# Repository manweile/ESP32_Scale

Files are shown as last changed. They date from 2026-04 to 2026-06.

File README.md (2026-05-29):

# ESP32 Propane Scale

Compact ESP32-based propane tank scale that measures tank weight, subtracts the tank tare, and reports the propane weight and fill percentage.

This version is serial monitor based, and serves as starting point for wifi and web ble versions.

## Versions

1. Serial monitor
2. Web BLE
3. Wifi

## Quick highlights

- Weighs tanks using four load cells + HX711 amplifier
- Supports automatic and manual calibration workflows
- Saves calibration/tare values to EEPROM
- Built with `arduino-cli` and VS Code tasks for rapid iteration

## Quick Start

1. Install Arduino CLI
2. Install Espressif toolchain
3. Install ESP32 board support and the HX711 library
4. Open this workspace in VS Code. Use the provided tasks to build/flash (see 'Tasks' section)
5. Edit `PropaneScale/config.h` to set the pins and default calibration/tare values before flashing
6. Connect to a serial console at `115200` to interact with the command interface

## Building and Uploading

Building & Uploading can be done with VS Code compound task calls:

- `ESP32 Thing Quick Compile & Quick Flash`
- `ESP32 Thing Clean Rebuild & Quick Flash`
- Refer to building and upload section for details

### Building

Building is being done via arduino-cli.

- Using arduino-cli for convenience
- Have experience with it
- Already installed and configured
- Precludes having to re-learn CMake & Ninja
- Use the included VS Code tasks: `ESP32 Thing Quick Compile`, `ESP32 Thing Clean Rebuild`
- The FQBN (full qualified board name) is hard coded because the project is esp32 specific
- Example arduino-cli build command (used by the tasks):

  ```bash
  arduino-cli compile -v --fqbn esp32:esp32:esp32thing PropaneScale
  ```

### Upload

Uploading is done via esptool.exe

- Planning on eventually using esp tools entirely for build and upload
- Since esp32 is only chip used, it is hard coded, as is the upload speed, write flash location, and binary file
- the *.ino.merged.bin file must be used for an esp32
- Use the include VS Code tasks:
  - `ESP32 Thing Quick Flash`
    - This task uses `esp32-thing-quick-flash.ps1` powershell script, which in turn calls `list_ports.py`
    - These scripts return the com port the esp32 thing is attached to
    - Example cli:

    ```bash
    esptool.exe --chip esp32 --port COM3 --baud 921600 write-flash -z 0x0 D:/MyArduino/Projects/ESP32_Scale/PropaneScale/build/esp32.esp32.esp32thing/PropaneScale.ino.merged.bin
    ```

  - `ESPTool ESP32 COMPort Merged Bin Upload`
    - This task needs com port import
    - The com port input uses `list_ports.py` directly
    - Example cli:

    ```bash
    esptool.exe --chip esp32 --port COM4 --baud 921600 write-flash -z 0x0 D:/MyArduino/Projects/ESP32_Scale/PropaneScale/build/esp32.esp32.esp32thing/PropaneScale.ino.merged.bin
    ```

## Configuration

- Edit `PropaneScale/config.h` to change:
  - `CLK_PIN`, `DOUT_PIN` (HX711 pins)
    - While these can be almost any of the available pins, using 16 & 17 so the JTAG pins (12, 13, 14, 15) remain open
  - `BAUD` (serial baud rate)
    - Needs to be 115200, as that is the hard coded default boot speed of the ESP32 Thing
    - using any other speed results in ascii garbage hen the REST button is hit
  - `DEF_CALIBRATION_FACTOR`
    - Computed by running SparkFun_HX711_Calibration.ino in examples directory and noting the value
  - `DEF_KNOWN_WEIGHT`
    - The sample weight used to compute the default calibration factor
  - `DEF_TANK_TARE`
    - midpoint of average 20 lb tank tares
  - `DEF_MAX_PROPANE`
    - the legal maximum of propane for 20 lb tank: 80% x 20 = 16

## Hardware Summary

- Microcontroller: SparkFun ESP32 Thing (DEV-13907)
- Amplifier: SparkFun HX711 (BOB-13879)
- Load cells: SparkFun 50 kg (SEN-10245) — 4x in a full-bridge arrangement

### HX711 pins (default)

| HX711 | ESP32 |
| --- | --- |
| CLK | GPIO 17 |
| DOUT | GPIO 16 |

## Serial Command Interface

- Commands:
  - `a` — Automatic calibration
  - `c` — Print current runtime values
  - `d` — Reset EEPROM value to default configuration
  - `e` — Print EEPROM values
  - `h` — Print menu
  - `m` — Manual calibration (use `+` / `-`, save with `s`)
  - `k` - Set known weight for calibrations (enter value, `s` to save)
  - `l` — Single reading of propane weight and level
  - `p` — Set tank tare (enter value, `s` to save)
  - `q` — Cancellation for all input workflows
  - `r` — Re-zero scale, `q` to force-confirm
  - `t` - Set tank tare (enter value, `s` to save)

## Output example

```text
Scale load: 39.5 lbs, Calculated propane: 15.7 lbs, Level: 65.4%
```

## Project Layout

- [PropaneScale](PropaneScale): main sketch
- `config.h` (pin and calibration constants)
- Documentation under the `Documentation/` folder
- Examples under the `Examples/` folder

## Development Notes

- This workspace includes tasks for build/flash and a Doxygen setup in `Documentation/Doxygen/`.
- See `Documentation/Copilot/` for notes and design plans.

Contributing

- Fixes, improvements, and pull requests welcome. Please open issues describing bugs or requested features.

License

- This repository does not include a license file. Add one if you intend to publish the code.

---
Updated README: streamlined quick-start, build tasks, and configuration notes.

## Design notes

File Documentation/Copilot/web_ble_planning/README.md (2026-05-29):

# Web BLE Planning (directory)

This directory is the canonical location for all Web Bluetooth planning artifacts for the PropaneScale project.

Place all new or updated web-ble planning files here, including:
- `web-bluetooth-plan.md` (high-level proposal and milestones)
- `asus-tab-a-test-checklist.md` (device-specific test checklists)
- `ble_test_vectors.md` (test payloads and vectors)
- `examples/` (client prototypes, sample pages)

Policy: until further notice, put web BLE documents and examples into this folder so they are easy to find and review.

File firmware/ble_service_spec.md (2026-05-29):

# BLE Service Specification — PropaneScale (Firmware)

This document defines exact UUIDs, characteristic properties, and payload formats for the BLE GATT service the `PropaneScale` ESP32 firmware will expose. This is a protocol specification only — no implementation is included.

Service
- Name: PropaneScale Service (custom)
- UUID (128-bit): 0000FEED-0000-1000-8000-00805F9B34FB

Characteristic summary (all UUIDs are 128-bit within same vendor base):
- Weight (Notify, Read) — UUID: 0000BE01-0000-1000-8000-00805F9B34FB
- Tare Command (Write Without Response) — UUID: 0000BE02-0000-1000-8000-00805F9B34FB
- Calibrate Command (Write) — UUID: 0000BE03-0000-1000-8000-00805F9B34FB
- Raw ADC (Notify, Read) — UUID: 0000BE04-0000-1000-8000-00805F9B34FB
- Sampling Rate (Read/Write) — UUID: 0000BE05-0000-1000-8000-00805F9B34FB
- Battery (Read, Notify) — UUID: 0000BE06-0000-1000-8000-00805F9B34FB
- Device Info / Version (Read) — UUID: 0000BE07-0000-1000-8000-00805F9B34FB

General encoding rules
- Endianness: Little-endian for multi-byte numeric fields.
- Numeric types: use standard sizes (uint8, int16, int32, uint16, uint32, float32 as IEEE-754 where indicated).
- Versioning: each notification payload starts with `uint8 version` (currently `1`).
- Sequence counter: optional `uint16 seq` included in streaming payloads to detect loss.
- All characteristic lengths are fixed where practical to simplify parsing.

Characteristic details

1) Weight — `0000BE01-...`
- Properties: Notify, Read
- Purpose: current processed weight in pounds (float32) with sign support.
- Payload (9 bytes):
  - byte 0: `uint8 version` (1)
  - byte 1-4: `float32 weight_lbs` — weight in pounds (IEEE‑754 float32, little-endian)
  - byte 5-6: `uint16 seq` — packet sequence number (wraps)
  - byte 7-8: `int16 reserved` — reserved (set 0)
- Example: weight = 12.345 lbs → payload fields:
  - `[version=0x01][float32 little-endian of 12.345][seq=0x0001][reserved=0x0000]`
  (Replace the float32 bytes with the IEEE‑754 little-endian representation for the value.)

2) Tare Command — `0000BE02-...`
- Properties: Write Without Response (fast), firmware acts immediately.
- Purpose: request firmware to perform tare (zero) operation.
- Payload (1 byte):
  - byte 0: `uint8 cmd` where 0x01 = TARE_NOW
- Example: to tare, client writes `[0x01]`.
- Security: firmware must validate source and rate-limit successive TARE requests (e.g., minimum 1s between tarries).

3) Calibrate Command — `0000BE03-...`
- Properties: Write (request-response via Device Info or event)
- Purpose: initiate calibration sequence. Two modes supported.
- Payload (6 bytes):
  - byte 0: `uint8 cmd` (0x01 = CAL_START_SINGLE_WEIGHT)
  - byte 1-4: `float32 mass_lbs` (mass in pounds for calibration reference; little-endian, IEEE‑754)
  - byte 5: `uint8 options` (bitmask reserved)
- Example: calibrate with a 2.20462 lb weight (~1 kg): `[0x01][<float32 LE bytes for 2.20462>][0x00]`
- Response: firmware writes a one-time Device Info/Version update or a separate calibration status event (can reuse Weight or Device Info characteristic to signal success/failure).

4) Raw ADC — `0000BE04-...`
- Properties: Notify, Read
- Purpose: transmit raw ADC counts (signed 32-bit) for debugging/advanced smoothing on client side.
- Payload (9 bytes):
  - byte 0: `uint8 version` (1)
  - byte 1-4: `int32 adc_counts` (LE)
  - byte 5-6: `uint16 seq`
  - byte 7-8: `int16 reserved`
- Note: ADC notifications can be sent at a higher rate but consider BLE throughput limits.

5) Sampling Rate — `0000BE05-...`
- Properties: Read, Write
- Purpose: allow client to read or set the sampling interval used by firmware for notifications.
- Payload (2 bytes):
  - `uint16 interval_ms` (little-endian) — notification interval in milliseconds. Range: 20..2000 (firmware enforces limits).
- Example: set 100 ms interval: `[0x64 0x00]`.

6) Battery — `0000BE06-...`
- Properties: Read, Notify
- Purpose: report battery level.
- Payload (3 bytes):
  - byte 0: `uint8 version` (1)
  - byte 1-2: `uint16 battery_mv` (millivolts, LE)
- Firmware should send periodic notifications on significant changes or on client request.

7) Device Info / Version — `0000BE07-...`
- Properties: Read
- Purpose: static device information and firmware version.
- Payload (variable up to 32 bytes, UTF-8 text): `manufacturer|model|fw_version|build` (pipe-separated)
- Example: `Acme|PropaneScale|v1.2.0|2026-05-19`

Operations & behaviors
- Discovery: client filters by Service UUID `0000FEED-0000-1000-8000-00805F9B34FB` during device request.
- Notifications: Weight and Raw ADC should include `seq` to permit loss detection. Clients should apply simple smoothing/filtering for UI.
- Rate limiting: Tare write requests must be rate-limited by firmware (recommended 1 second cooldown).
- Atomicity: firmware must apply commands atomically; if calibrate is in-progress, reject new calibrate requests with a status code via Device Info or a writeable status char (not defined here).

Security recommendations (firmware-facing)
- Optionally implement a simple application-layer token flow:
  - `auth` token stored in NVS; client must write a `0xA5` + token sequence to a secure characteristic before control char writes accepted. (Left as optional — implement only if needed.)
- Validate and bound incoming values (sampling interval range, calibration mass limits).

Versioning & extensibility
- Always increment `version` byte on payload format changes. Clients must check `version` and refuse or attempt fallback if unsupported.
- Reserve characteristic UUIDs `0000BE08..0000BE0F` for future use.

Testing notes
- Provide an example test vector file for each characteristic (hex sequences) included in `Documentation/Copilot/examples` (to be created separately).
- Validate end-to-end with Web Bluetooth client and a BLE explorer app (nRF Connect) before integrating UI control flows.

Change log
- 2026-05-19: Initial spec created by Copilot (proposal).

---

File location suggestions:
- Add this spec to `firmware/ble_service_spec.md` (this file).
- Add simple example packets to `Documentation/Copilot/examples/ble_test_vectors.md` next.

If you'd like, I can now scaffold `Documentation/Copilot/examples/ble_test_vectors.md` and a minimal `web-bluetooth-client/` example. Which should I do next?

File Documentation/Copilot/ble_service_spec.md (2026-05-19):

# BLE Service Specification — PropaneScale (Firmware)

This document defines exact UUIDs, characteristic properties, and payload formats for the BLE GATT service the `PropaneScale` ESP32 firmware will expose. This is a protocol specification only — no implementation is included.

Service
- Name: PropaneScale Service (custom)
- UUID (128-bit): 0000FEED-0000-1000-8000-00805F9B34FB

Characteristic summary (all UUIDs are 128-bit within same vendor base):
- Weight (Notify, Read) — UUID: 0000BE01-0000-1000-8000-00805F9B34FB
- Tare Command (Write Without Response) — UUID: 0000BE02-0000-1000-8000-00805F9B34FB
- Calibrate Command (Write) — UUID: 0000BE03-0000-1000-8000-00805F9B34FB
- Raw ADC (Notify, Read) — UUID: 0000BE04-0000-1000-8000-00805F9B34FB
- Sampling Rate (Read/Write) — UUID: 0000BE05-0000-1000-8000-00805F9B34FB
- Battery (Read, Notify) — UUID: 0000BE06-0000-1000-8000-00805F9B34FB
- Device Info / Version (Read) — UUID: 0000BE07-0000-1000-8000-00805F9B34FB

General encoding rules
- Endianness: Little-endian for multi-byte numeric fields.
- Numeric types: use standard sizes (uint8, int16, int32, uint16, uint32, float32 as IEEE-754 where indicated).
- Versioning: each notification payload starts with `uint8 version` (currently `1`).
- Sequence counter: optional `uint16 seq` included in streaming payloads to detect loss.
- All characteristic lengths are fixed where practical to simplify parsing.

Characteristic details

1) Weight — `0000BE01-...`
- Properties: Notify, Read
- Purpose: current processed weight in grams (scaled integer) with sign support.
- Payload (9 bytes):
  - byte 0: `uint8 version` (1)
  - byte 1-4: `int32 weight_mg` — weight in milligrams (signed, little-endian)
  - byte 5-6: `uint16 seq` — packet sequence number (wraps)
  - byte 7-8: `int16 reserved` — reserved (set 0)
- Example: weight = 1234.5 g → weight_mg = 1234500 = 0x12 CA 35 00 (LE) so payload:
  - [0x01][0x64][0x1A][0x12][0x00][0x00][0x01][0x00][0x00]
  (example seq=1)

2) Tare Command — `0000BE02-...`
- Properties: Write Without Response (fast), firmware acts immediately.
- Purpose: request firmware to perform tare (zero) operation.
- Payload (1 byte):
  - byte 0: `uint8 cmd` where 0x01 = TARE_NOW
- Example: to tare, client writes `[0x01]`.
- Security: firmware must validate source and rate-limit successive TARE requests (e.g., minimum 1s between tarries).

3) Calibrate Command — `0000BE03-...`
- Properties: Write (request-response via Device Info or event)
- Purpose: initiate calibration sequence. Two modes supported.
- Payload (6 bytes):
  - byte 0: `uint8 cmd` (0x01 = CAL_START_SINGLE_WEIGHT)
  - byte 1-4: `uint32 mass_g` (mass in grams for calibration reference; little-endian)
  - byte 5: `uint8 options` (bitmask reserved)
- Example: calibrate with a 500 g weight: `[0x01][0xF4][0x01][0x00][0x00][0x00]` (500 = 0x01F4)
- Response: firmware writes a one-time Device Info/Version update or a separate calibration status event (can reuse Weight or Device Info characteristic to signal success/failure).

4) Raw ADC — `0000BE04-...`
- Properties: Notify, Read
- Purpose: transmit raw ADC counts (signed 32-bit) for debugging/advanced smoothing on client side.
- Payload (9 bytes):
  - byte 0: `uint8 version` (1)
  - byte 1-4: `int32 adc_counts` (LE)
  - byte 5-6: `uint16 seq`
  - byte 7-8: `int16 reserved`
- Note: ADC notifications can be sent at a higher rate but consider BLE throughput limits.

5) Sampling Rate — `0000BE05-...`
- Properties: Read, Write
- Purpose: allow client to read or set the sampling interval used by firmware for notifications.
- Payload (2 bytes):
  - `uint16 interval_ms` (little-endian) — notification interval in milliseconds. Range: 20..2000 (firmware enforces limits).
- Example: set 100 ms interval: `[0x64 0x00]`.

6) Battery — `0000BE06-...`
- Properties: Read, Notify
- Purpose: report battery level.
- Payload (3 bytes):
  - byte 0: `uint8 version` (1)
  - byte 1-2: `uint16 battery_mv` (millivolts, LE)
- Firmware should send periodic notifications on significant changes or on client request.

7) Device Info / Version — `0000BE07-...`
- Properties: Read
- Purpose: static device information and firmware version.
- Payload (variable up to 32 bytes, UTF-8 text): `manufacturer|model|fw_version|build` (pipe-separated)
- Example: `Acme|PropaneScale|v1.2.0|2026-05-19`

Operations & behaviors
- Discovery: client filters by Service UUID `0000FEED-0000-1000-8000-00805F9B34FB` during device request.
- Notifications: Weight and Raw ADC should include `seq` to permit loss detection. Clients should apply simple smoothing/filtering for UI.
- Rate limiting: Tare write requests must be rate-limited by firmware (recommended 1 second cooldown).
- Atomicity: firmware must apply commands atomically; if calibrate is in-progress, reject new calibrate requests with a status code via Device Info or a writeable status char (not defined here).

Security recommendations (firmware-facing)
- Optionally implement a simple application-layer token flow:
  - `auth` token stored in NVS; client must write a `0xA5` + token sequence to a secure characteristic before control char writes accepted. (Left as optional — implement only if needed.)
- Validate and bound incoming values (sampling interval range, calibration mass limits).

Versioning & extensibility
- Always increment `version` byte on payload format changes. Clients must check `version` and refuse or attempt fallback if unsupported.
- Reserve characteristic UUIDs `0000BE08..0000BE0F` for future use.

Testing notes
- Provide an example test vector file for each characteristic (hex sequences) included in `Documentation/Copilot/examples` (to be created separately).
- Validate end-to-end with Web Bluetooth client and a BLE explorer app (nRF Connect) before integrating UI control flows.

Change log
- 2026-05-19: Initial spec created by Copilot (proposal).

---

File location suggestions:
- Add this spec to `firmware/ble_service_spec.md` (this file).
- Add simple example packets to `Documentation/Copilot/examples/ble_test_vectors.md` next.

If you'd like, I can now scaffold `Documentation/Copilot/examples/ble_test_vectors.md` and a minimal `web-bluetooth-client/` example. Which should I do next?

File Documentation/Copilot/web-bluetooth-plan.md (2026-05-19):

# Web Bluetooth Interface — Proposal for ESP32 Scale

Reference: https://randomnerdtutorials.com/esp32-web-bluetooth/

## Purpose
Propose a phased plan for adding a Web Bluetooth client to interact with the ESP32-based `PropaneScale` project. The goal is a minimal, secure, cross-platform web UI that can connect to the device, show live weight, perform tare/calibration, and receive telemetry (battery, sampling rate, raw ADC) with low latency.

## Constraints & Notes
- Web Bluetooth requires HTTPS (or localhost). Web Bluetooth support is strongest in Chromium-based browsers on desktop and Android. iOS Safari has limited/no support.
- The ESP32 will act as a BLE peripheral exposing a custom GATT service.
- Follow guidance from the Random Nerd Tutorials article above for connection and characteristic examples.

## High-Level Milestones
- Draft API (GATT) and message formats
- Design web UI/UX and connection flows
- Implement firmware GATT service on ESP32
- Implement Web Bluetooth client (connect, read, notify, write)
- Test across browsers/devices, add reconnection logic
- Document usage and publish examples

## Proposed GATT Service & Characteristics
Custom Service UUID: `0000FEED-0000-1000-8000-00805F9B34FB` (example — choose/re-roll)

Characteristics (suggested):
- Weight (Notify, Read) — int32 or float (scaled grams) — UUID: (eg) `0000BE01-0000-1000-8000-00805F9B34FB`
- Tare Command (Write) — write-only command (0x01 = tare) — UUID: `0000BE02-...`
- Calibrate Command (Write) — write weight or command sequence — UUID: `0000BE03-...`
- Raw ADC / Loadcell (Notify, Read) — int32 — UUID: `0000BE04-...`
- Sampling Rate (Read/Write) — uint16 ms or hz — UUID: `0000BE05-...`
- Battery (Read, Notify) — uint8/uint16 percent or mV — UUID: `0000BE06-...`

Design notes:
- Use Notify for live streaming (weight, raw ADC, battery). Use Read for on-demand values.
- Keep characteristic payloads small and fixed-length for predictable parsing.
- Use little-endian numeric encodings and include a simple version byte in payloads to allow future changes.

## Web App Architecture
- Single-page web app using Web Bluetooth API (vanilla JS or lightweight framework like Preact).
- Components: Device selector & connect button, Live weight display, Controls (Tare, Calibrate, Sampling Rate), Telemetry panel (battery, raw ADC), Logs & error display.
- On connect: discover service by UUID, subscribe to notify characteristics, start a local UI update loop throttled to UI frame rate (e.g., 50–100 ms updates).
- Reconnection: remember device id (if supported), attempt reconnect on disconnect with exponential backoff.

## UX Flow
1. User opens app on HTTPS origin or localhost.
2. Click `Connect` → browser device chooser (filtered by service UUID).
3. After connect: show device name, current weight, live updates.
4. Controls: `Tare` (writes to Tare characteristic), `Calibrate` (guided dialog writing mass and running calibration), `Set Sampling Rate` (write to characteristic).
5. Status indicators: connection state, last packet timestamp, battery.
6. Error handling UI for permission denied, unsupported browser, and BLE disconnects.

## Security & Permissions
- Use HTTPS for deployed web app. For local testing, `localhost` is acceptable.
- Limit device discovery to the specific custom service UUID to reduce accidental pairing.
- Consider simple application-level auth: on first connect generate a short pairing token stored in device NVS; require token write before control commands are honored.
- Recommend implementing firmware-side rate limiting and command validation to guard against accidental/malicious repeated writes.

## Data Format & Protocol Suggestions
- All numeric values little-endian. Add `version` byte at start of notifications.
- Weight payload example (5 bytes): [version=1][int32 weight_mg]
- Tare/Command payloads: single byte command or small struct [cmd][arg...].
- Include timestamp or sequence counter occasionally for loss detection.

## Testing Matrix
- Browsers: Chrome/Edge (desktop), Chrome on Android; test fallback behavior on Firefox and Safari (report unsupported features).
- Devices: Windows 10/11 laptops with BLE, Android phones, MacBooks with BLE.
- Test scenarios: connect/disconnect, rapid updates, write commands during streaming, OTA of calibration, power/battery low notifications.

## Performance & Latency
- Aim for notify intervals <= 100 ms for a responsive UI.
- If raw ADC is noisy, perform smoothing on the client or send averaged values from firmware.
- Measure end-to-end latency (weight sample → BLE notify → UI render) and tune characteristic update intervals accordingly.

## Deliverables
- `web-bluetooth-client/` example folder with a minimal SPA (not implemented in this proposal)
- `firmware/ble_service_spec.md` documenting UUIDs and payloads
- Integration test checklist and example test scripts
- User guide: how to host (HTTPS), how to connect, browser compatibility notes

## Risks & Mitigations
- iOS lack of Web Bluetooth support: provide native fallback (e.g., small native Android app) or document limitations.
- BLE limits: throughput constrained — prefer compact payloads and server-side aggregation.
- Security: BLE pairing is limited — implement app-layer simple token exchange.

## Estimated Effort (Rough)
- Design & spec: 1–2 days
- Firmware implementation & unit tests: 2–4 days
- Web client MVP: 2–3 days
- Cross-device testing & polish: 1–2 days

## References
- Random Nerd Tutorials: ESP32 + Web Bluetooth — https://randomnerdtutorials.com/esp32-web-bluetooth/
- Web Bluetooth API docs: https://developer.mozilla.org/en-US/docs/Web/API/Web_Bluetooth_API

---

If you want, I can now create the `firmware/ble_service_spec.md` stub and an example characteristic definition file, or scaffold a minimal client sample in `Documentation/Copilot/examples` — say the word and I’ll proceed.

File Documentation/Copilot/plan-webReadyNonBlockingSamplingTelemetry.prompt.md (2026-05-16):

**Plan: Web-Ready Non-blocking Sampling & Telemetry**

TL;DR - Replace blocking HX711 sampling with a non-blocking start/poll/get sampler, adapt workflows to poll from `loop()`/ticks, and introduce a telemetry wrapper that forwards structured one-line messages to both Serial (for debugging) and a web telemetry buffer/WebSocket. This preserves the serial monitor while enabling a web interface.

**Steps**
1. Implement non-blocking sampler in `src/scale_io.h` / `src/scale_io.cpp`: add `startSampleBatch(n)`, `pollSample()`, `isSampleDone()`, `getSampleResult()`; use `is_ready()` and read one sample per `pollSample()` call. (*depends on step 2*)
2. Refactor workflows to use the new sampler: change callers in `src/workflows/*` (calibration_workflow.cpp, level_workflow.cpp, startup_tare_workflow.cpp) to `startSampleBatch()` and poll from their `tick*()` functions instead of calling `readAveragedUnits()` directly.
3. Add `telemetry_write()` helper and small ring buffer in `src/scale_io.cpp` (or new `telemetry.cpp`) that enqueues one-line JSON/CSV lines and conditionally forwards human-readable messages to Serial when a debug flag is enabled; use `Serial.availableForWrite()` checks before immediate writes.
4. Add lightweight web telemetry endpoints: a JSON HTTP endpoint for last N samples and an `AsyncWebSocket` push path (reuse code from the example).
5. Throttle and coalesce telemetry emissions (e.g., publish rate ~1 Hz) and expose runtime config.
6. Validation: measure loop latency, verify Serial output order and content, verify web telemetry matches Serial, and verify workflows produce consistent results.

**Relevant files**
- [PropaneScale/PropaneScale.ino](PropaneScale/PropaneScale.ino) — adapt main loop / tick calls.
- [PropaneScale/src/scale_io.h](src/scale_io.h) — declare new sampler API.
- [PropaneScale/src/scale_io.cpp](src/scale_io.cpp) — refactor blocking `readAveragedUnits()`.
- [PropaneScale/src/workflows/calibration_workflow.cpp](src/workflows/calibration_workflow.cpp) — update to poll-based sampling.
- [PropaneScale/src/workflows/level_workflow.cpp](src/workflows/level_workflow.cpp) — update to poll-based sampling.
- [PropaneScale/src/workflows/startup_tare_workflow.cpp](src/workflows/startup_tare_workflow.cpp) — update to poll-based sampling.
- [PropaneScale/src/commands.cpp](src/commands.cpp) and [PropaneScale/src/app_startup.cpp](src/app_startup.cpp) — route prints through telemetry helper.
- [Examples/mine/copilot_scale.ino](Examples/mine/copilot_scale.ino) — webserver/WebSocket reference.

**Verification**
- Measure `loop()` timing to confirm blocking removed and responsiveness improved.
- Confirm Serial monitor still shows startup, prompts, and important events in order.
- Confirm web endpoint / WebSocket receive structured telemetry matching Serial.
- Confirm calibration/level results remain within acceptable tolerances.

**Decisions & Assumptions**
- Keep Serial monitor enabled by default; telemetry will forward human-readable messages conditionally.
- Use one-line JSON (recommended) or CSV for telemetry lines.
- Do not change baud or strip Serial in compile.

**Further Considerations**
1. JSON vs CSV? I recommend JSON for extensibility.
2. Use `AsyncWebSocket` to avoid blocking.
3. I can implement the non-blocking sampler and update `src/workflows/level_workflow.cpp` as a proof-of-concept — shall I proceed with that patch?

**Mobile & Offline Considerations**

- Local-first connectivity: assume the phone may have limited or no cellular coverage. Design the web interface to work entirely over a local Wi-Fi connection between the phone and the ESP32 (station or AP mode) with no cloud dependency.
- Dual connectivity modes: support both STA (ESP32 joins existing Wi-Fi) and AP mode (ESP32 hosts) with a simple captive-portal or QR-code setup flow to simplify pairing on a phone.
- Minimal, low-bandwidth UI: serve a very small PWA-style frontend (tiny HTML/CSS/vanilla JS) to minimize download size and loading time on mobile data or when caching is required.
- Offline-capable shell: make the frontend cache the UI shell and static assets (Service Worker) so the app loads from local cache even if cellular is unavailable; keep cached assets small to fit ESP32 storage limits.
- Resilient telemetry transport: use WebSocket with automatic reconnect and a simple HTTP polling fallback; keep payloads compact (one-line JSON, delta updates) and allow the client to request coarser update intervals when bandwidth is constrained.
- Coalesced & delta updates: publish only changed fields or compact deltas rather than full verbose messages; this reduces airtime and keeps mobile responsiveness higher.
- Explicit user controls: provide UI toggles for publish frequency, verbose vs compact output, and an option to mirror every telemetry line to Serial or to only show critical events on Serial.
- UX feedback: show clear connection status, last-updated timestamp, and allow the user to switch to AP/setup mode from the UI (or via a hardware button) when no network is available.
- Security & privacy: keep authentication lightweight and local (short-lived tokens or device-paired keys) to avoid relying on external identity providers when offline.
- Testing matrix: validate the full experience on iOS Safari and Android Chrome in airplane mode and in local Wi-Fi-only scenarios (AP mode and STA with no upstream internet).

These mobile-specific constraints reinforce earlier choices: prefer one-line JSON telemetry (item 12), non-blocking sampling (item 1), and a small `telemetry_write()` that can both mirror to Serial and feed the web buffer with minimal bandwidth.

Update 2: Priority (High → Low)

High
- Item 1 — Split blocking measurement from async acquisition: Recommended / High priority. Implement a non-blocking HX711 sampler (`startSampleBatch`, `pollSample`, `isSampleDone`, `getSampleResult`) and update workflows to poll once-per-loop tick.

High‑Medium
- Item 12 — Consolidate per-loop status into a single structured line: Deferred / Recommended for web phase. Standardize on one-line JSON for both Serial and WebSocket.

Medium
- Item 2 — Replace switch-to-string with lookup tables: Worth doing when editing diagnostic prints.
- Item 4 — Adaptive thresholds (hysteresis + debounce): Useful after sampler refactor.
- Item 5 — Fast/slow sampling profiles: Define after non-blocking sampler exists.

Medium‑Low
- Item 8 — Move high-frequency math to integer forms: Consider after profiling.

Low
- Item 6 — Cache rarely changing computed values: Optional micro-optimizations.

Dropped / Not applicable
- Item 7 — Minimize EEPROM commits: Dropped (user-driven writes).
- Item 9 — Baud change: Not applicable (ROM/boot constraints).
- Item 10 — Tick output rate-limiting: Dropped (no net benefit for current flow).

Next immediate action: implement Item 1 (non-blocking sampler) and add `telemetry_write()` to emit one-line JSON to Serial and the web buffer.

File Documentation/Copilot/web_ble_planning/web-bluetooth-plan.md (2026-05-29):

# Web Bluetooth Interface — Proposal for ESP32 Scale

Reference: https://randomnerdtutorials.com/esp32-web-bluetooth/

## Purpose
Propose a phased plan for adding a Web Bluetooth client to interact with the ESP32-based `PropaneScale` project. The goal is a minimal, secure, cross-platform web UI that can connect to the device, show live weight, perform tare/calibration, and receive telemetry (battery, sampling rate, raw ADC) with low latency.

## Constraints & Notes
- Web Bluetooth requires HTTPS (or localhost). Web Bluetooth support is strongest in Chromium-based browsers on desktop and Android. iOS Safari has limited/no support.
- The ESP32 will act as a BLE peripheral exposing a custom GATT service.
- Follow guidance from the Random Nerd Tutorials article above for connection and characteristic examples.

### Browser compatibility note
- Random Nerd Tutorials notes that Web Bluetooth has been implemented in Chrome, Edge, Opera, and Firefox and is supported on Android and Windows. In practice, Chrome on Android provides the most consistent experience; Firefox on Android may work on some devices/versions but is less consistent and sometimes requires specific browser builds or flags. Test both browsers on your device and prefer Chrome for primary support.

## High-Level Milestones
- Draft API (GATT) and message formats
- Design web UI/UX and connection flows
- Implement firmware GATT service on ESP32
- Implement Web Bluetooth client (connect, read, notify, write)
- Test across browsers/devices, add reconnection logic
- Document usage and publish examples

## Proposed GATT Service & Characteristics
Custom Service UUID: `0000FEED-0000-1000-8000-00805F9B34FB` (example — choose/re-roll)

Characteristics (suggested):
- Weight (Notify, Read) — int32 or float (scaled grams) — UUID: (eg) `0000BE01-0000-1000-8000-00805F9B34FB`
- Tare Command (Write) — write-only command (0x01 = tare) — UUID: `0000BE02-...`
- Calibrate Command (Write) — write weight or command sequence — UUID: `0000BE03-...`
- Raw ADC / Loadcell (Notify, Read) — int32 — UUID: `0000BE04-...`
- Sampling Rate (Read/Write) — uint16 ms or hz — UUID: `0000BE05-...`
- Battery (Read, Notify) — uint8/uint16 percent or mV — UUID: `0000BE06-...`

Design notes:
- Use Notify for live streaming (weight, raw ADC, battery). Use Read for on-demand values.
- Keep characteristic payloads small and fixed-length for predictable parsing.
- Use little-endian numeric encodings and include a simple version byte in payloads to allow future changes.

## Web App Architecture
- Single-page web app using Web Bluetooth API (vanilla JS or lightweight framework like Preact).
- Components: Device selector & connect button, Live weight display, Controls (Tare, Calibrate, Sampling Rate), Telemetry panel (battery, raw ADC), Logs & error display.
- On connect: discover service by UUID, subscribe to notify characteristics, start a local UI update loop throttled to UI frame rate (e.g., 50–100 ms updates).
- Reconnection: remember device id (if supported), attempt reconnect on disconnect with exponential backoff.

## UX Flow
1. User opens app on HTTPS origin or localhost.
2. Click `Connect` → browser device chooser (filtered by service UUID).
3. After connect: show device name, current weight, live updates.
4. Controls: `Tare` (writes to Tare characteristic), `Calibrate` (guided dialog writing mass and running calibration), `Set Sampling Rate` (write to characteristic).
5. Status indicators: connection state, last packet timestamp, battery.
6. Error handling UI for permission denied, unsupported browser, and BLE disconnects.

## Security & Permissions
- Use HTTPS for deployed web app. For local testing, `localhost` is acceptable.
- Limit device discovery to the specific custom service UUID to reduce accidental pairing.
- Consider simple application-level auth: on first connect generate a short pairing token stored in device NVS; require token write before control commands are honored.
- Recommend implementing firmware-side rate limiting and command validation to guard against accidental/malicious repeated writes.

## Data Format & Protocol Suggestions
- All numeric values little-endian. Add `version` byte at start of notifications.
- Weight payload example (5 bytes): [version=1][int32 weight_mg]
- Tare/Command payloads: single byte command or small struct [cmd][arg...].
- Include timestamp or sequence counter occasionally for loss detection.

- ## Testing Matrix
- Browsers: Chrome/Edge (desktop), Chrome on Android; test fallback behavior on Firefox and Safari (report unsupported features). Note: per Random Nerd Tutorials, Firefox on Android has implemented Web Bluetooth and may work — verify on your tablet.
- Devices: Windows 10/11 laptops with BLE, Android phones, MacBooks with BLE.
- Test scenarios: connect/disconnect, rapid updates, write commands during streaming, OTA of calibration, power/battery low notifications.

### Asus Tab A (Android) — explicit test steps
1. Use Chrome on the tablet as primary test browser; have Firefox available for comparison.
2. Verify Web Bluetooth API availability in the browser console:

```javascript
// open DevTools or remote debugger and run
console.log('navigator.bluetooth' in window, navigator.bluetooth !== undefined);
```

3. If `navigator.bluetooth` is false/undefined in Firefox, try Chrome. Some Firefox builds may expose Web Bluetooth only behind experimental flags; in that case prefer Chrome.
4. Host the test app over HTTPS (GitHub Pages or local HTTPS server). For quick local testing you can run a simple HTTP server on a desktop and access via Chrome on Android if served over HTTPS or via `localhost` on the device.
5. Use `nRF Connect` (Android) to inspect advertised service UUIDs and characteristic presence before connecting from the browser.
6. Test these scenarios on the tablet: connect, enable notifications, receive ~100 ms updates, send `Tare` write, send `Calibrate` write, disconnect/reconnect.
7. Record browser version, Android version, and any required flags if Firefox needed special configuration.

## Performance & Latency
- Aim for notify intervals <= 100 ms for a responsive UI.
- If raw ADC is noisy, perform smoothing on the client or send averaged values from firmware.
- Measure end-to-end latency (weight sample → BLE notify → UI render) and tune characteristic update intervals accordingly.

## Deliverables
- `web-bluetooth-client/` example folder with a minimal SPA (not implemented in this proposal)
- `firmware/ble_service_spec.md` documenting UUIDs and payloads
- Integration test checklist and example test scripts
- User guide: how to host (HTTPS), how to connect, browser compatibility notes

## Risks & Mitigations
- iOS lack of Web Bluetooth support: provide native fallback (e.g., small native Android app) or document limitations.
- BLE limits: throughput constrained — prefer compact payloads and server-side aggregation.
- Security: BLE pairing is limited — implement app-layer simple token exchange.

## Estimated Effort (Rough)
- Design & spec: 1–2 days
- Firmware implementation & unit tests: 2–4 days
- Web client MVP: 2–3 days
- Cross-device testing & polish: 1–2 days

## References
- Random Nerd Tutorials: ESP32 + Web Bluetooth — https://randomnerdtutorials.com/esp32-web-bluetooth/
- Web Bluetooth API docs: https://developer.mozilla.org/en-US/docs/Web/API/Web_Bluetooth_API

---

If you want, I can now create the `firmware/ble_service_spec.md` stub and an example characteristic definition file, or scaffold a minimal client sample in `Documentation/Copilot/examples` — say the word and I’ll proceed.

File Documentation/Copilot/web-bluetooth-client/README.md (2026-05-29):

# Web Bluetooth Client (scaffold)

Minimal scaffold for a Web Bluetooth client to talk to the PropaneScale ESP32.

Purpose
- Provide a tiny single-file SPA skeleton that demonstrates the UI layout and where BLE logic should live.
- Not implemented: this is a scaffold only; connection and full feature logic are left as TODOs.

Run (local dev)
- Serve the folder over `localhost` (HTTPS required for Web Bluetooth in many browsers). For quick testing you can run a local server on the development machine and open the page there.

Example (Python 3):
```bash
python -m http.server 8000
# then open http://localhost:8000 in a browser
```

Files
- `index.html` — UI skeleton
- `app.js` — client-side JS stubs and helpers
- `styles.css` — minimal styling

Next steps
- Implement BLE connect/disconnect, subscribe to notifications, and wire controls to write characteristics.
- Add reconnection/backoff and permission/error handling.

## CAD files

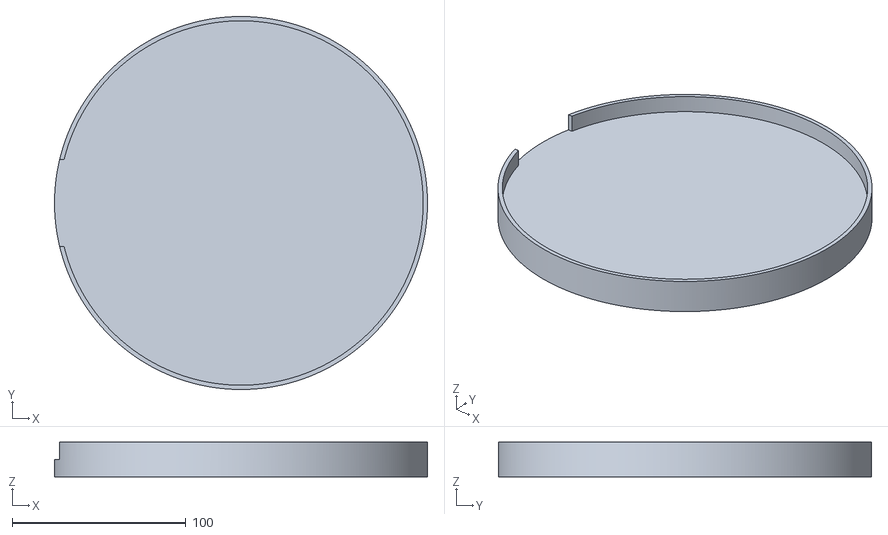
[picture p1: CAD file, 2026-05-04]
Documentation/3D/Bottom Plate v1.stl
215.0 x 215.0 x 20.0

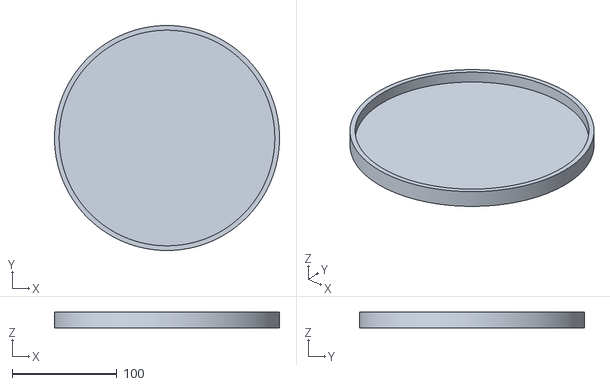
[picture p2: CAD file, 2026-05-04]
Documentation/3D/Top Plate v1.stl
215.0 x 215.0 x 15.0

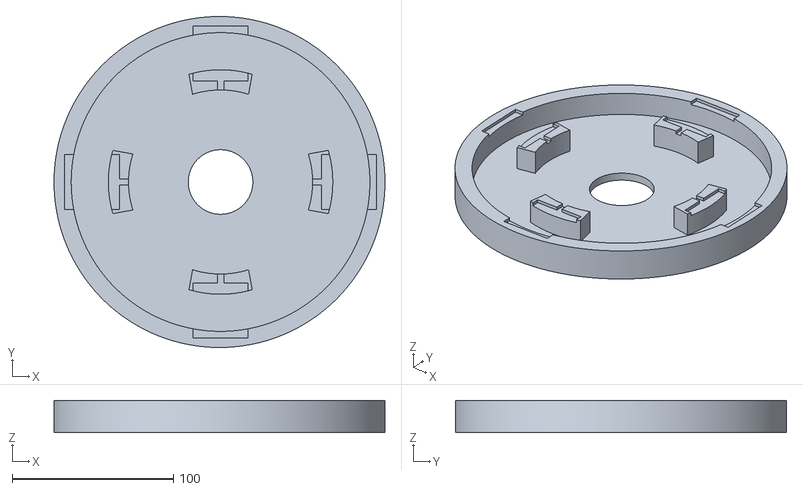
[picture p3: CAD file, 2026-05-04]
Documentation/3D/Sensor Plate v1.stl
205.0 x 205.0 x 20.0

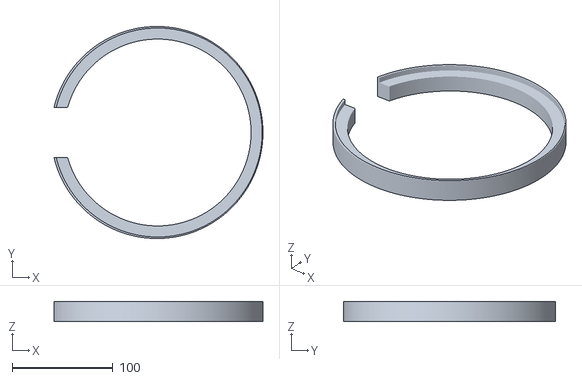
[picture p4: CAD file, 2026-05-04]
Documentation/3D/Test Stand v1.stl
207.0 x 210.0 x 20.0

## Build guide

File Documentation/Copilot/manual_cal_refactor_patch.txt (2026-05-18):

Minimal Nested `ManualCal` Refactor Proposal

Summary:
- Move manual-only `CalContext` fields into a nested `ManualCal` struct named `manual`.
- Keep shared workflow fields at top-level in `CalContext`.
- Update call sites to `calCtx.manual.<field>`.

Why:
- Separates manual-specific state from shared state used by AUTO/REZERO.
- Clarifies intent and reduces accidental cross-mode access.
- Low-risk, minimal-churn refactor.

Proposed `CalContext` layout (copy into PropaneScale/src/workflows/workflows_contexts.h):

struct CalContext {
  // Shared across modes
  CalMode       mode                      = CalMode::NONE;  /**< current calibration mode */
  CalState      state                     = CalState::IDLE; /**< current state within workflow */
  unsigned long stateStartMs              = 0;              /**< millis() when current state was entered */
  int           stableEmptyChecks         = 0;              /**< consecutive empty-scale readings in WAIT_EMPTY */
  int           loadDetectChecks          = 0;              /**< consecutive above-threshold load detection checks */
  float         loadDetectThreshold       = 0.0f;           /**< noise-derived threshold for weight detection */
  float         measuredUnits             = 0.0f;           /**< last averaged reading in pounds */

  // Manual-mode specific subgroup
  struct ManualCal {
    float adjustmentStep            = 0.0f;           /**< manual mode: current factor nudge size */
    bool  hasManualDisplay          = false;          /**< manual mode: whether we have a prior display snapshot */
    int   lastDirection             = 0;              /**< manual mode: +1 = last press +, -1 = last press - */
    int   lastFactorHundredth       = 0;              /**< manual mode: last displayed factor, scaled by 100 */
    int   lastReadingTenth          = 0;              /**< manual mode: last displayed reading, scaled by 10 */
    int   lastStepTenThousandth     = 0;              /**< manual mode: last displayed step, scaled by 10000 */
    float minStep                   = 0.0f;           /**< manual mode: floor for adjustmentStep */
    float originalCalibrationFactor = 0.0f;           /**< manual mode: calibration factor captured at start */
  } manual;
};

Migration steps (mechanical):
1) Add the nested `ManualCal` struct into `PropaneScale/src/workflows/workflows_contexts.h` replacing the existing `CalContext` definition. Keep the shared fields unchanged.

2) Update call sites to reference the nested `manual` member. The following fields must be updated:
   - adjustmentStep
   - hasManualDisplay
   - lastDirection
   - lastFactorHundredth
   - lastReadingTenth
   - lastStepTenThousandth
   - minStep
   - originalCalibrationFactor

Precise PowerShell search/replace commands (run from the repository root):

# NOTE: these commands rewrite files in-place. Run under Git and review diffs before committing.
# They operate on .cpp and .h files under the workspace. Adjust -Path filter if needed.

Get-ChildItem -Path . -Recurse -Include *.cpp,*.h | ForEach-Object {
  (Get-Content $_.FullName) |
    ForEach-Object {
      $_ -replace 'calCtx\\.adjustmentStep', 'calCtx.manual.adjustmentStep' `
         -replace 'calCtx\\.hasManualDisplay', 'calCtx.manual.hasManualDisplay' `
         -replace 'calCtx\\.lastDirection', 'calCtx.manual.lastDirection' `
         -replace 'calCtx\\.lastFactorHundredth', 'calCtx.manual.lastFactorHundredth' `
         -replace 'calCtx\\.lastReadingTenth', 'calCtx.manual.lastReadingTenth' `
         -replace 'calCtx\\.lastStepTenThousandth', 'calCtx.manual.lastStepTenThousandth' `
         -replace 'calCtx\\.minStep', 'calCtx.manual.minStep' `
         -replace 'calCtx\\.originalCalibrationFactor', 'calCtx.manual.originalCalibrationFactor'
    } | Set-Content $_.FullName
}

Alternative: single-purpose replacements (safer, one at a time):

(Get-ChildItem -Path . -Recurse -Include *.cpp,*.h) | ForEach-Object {
  (Get-Content $_.FullName) -replace 'calCtx\\.adjustmentStep', 'calCtx.manual.adjustmentStep' | Set-Content $_.FullName
}

Repeat for each symbol replacing the left/right sides.

Manual patch example for `PropaneScale/src/workflows/workflows_contexts.h` (apply by hand or via your patch tool):

--- workflows_contexts.h (original excerpt)
@@
 struct CalContext {
-  float         adjustmentStep            = 0.0f;           /**< manual mode: current factor nudge size */
-  bool          hasManualDisplay          = false;          /**< manual mode: whether we have a prior display snapshot to compare against */
-  int           lastDirection             = 0;              /**< manual mode: +1 = last press +, -1 = last press - */
-  int           lastFactorHundredth       = 0;              /**< manual mode: last displayed factor, scaled by 100 (2 decimal places) */
-  int           lastReadingTenth          = 0;              /**< manual mode: last displayed reading, scaled by 10 (1 decimal place) */
-  int           lastStepTenThousandth     = 0;              /**< manual mode: last displayed step, scaled by 10000 (4 decimal places) */
-  int           loadDetectChecks          = 0;              /**< calibration mode: consecutive above-threshold load detection checks */
-  float         loadDetectThreshold       = 0.0f;           /**< noise-derived threshold for weight detection */
-  float         measuredUnits             = 0.0f;           /**< last averaged reading in pounds */
-  float         minStep                   = 0.0f;           /**< manual mode: floor for adjustmentStep */
-  CalMode       mode                      = CalMode::NONE;  /**< current calibration mode, or NONE when not in a calibration workflow */
-  float         originalCalibrationFactor = 0.0f;           /**< manual mode: calibration factor captured at start for cancel/restore */
-  int           stableEmptyChecks         = 0;              /**< consecutive empty-scale readings in WAIT_EMPTY */
-  CalState      state                     = CalState::IDLE; /**< current state within the calibration workflow */
-  unsigned long stateStartMs              = 0;              /**< millis() when current state was entered */
-};
+  // (Replace the whole contents with the new layout shown in the proposal above.)
+
--- end example

Build & test checklist:
- Run a Git diff and review changes.
- Build with your existing tasks (e.g. `ESP32 Thing Quick Compile`).
- Test manual calibration and auto calibration + rezero on device.

Suggested commit message:
refactor(workflows): nest manual-only calibration fields into CalContext::ManualCal

---
File created by Copilot assistant: Documentation/Copilot/manual_cal_refactor_patch.txt

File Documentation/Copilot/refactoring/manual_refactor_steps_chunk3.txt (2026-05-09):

ESP32 PropaneScale Manual Refactor Guide (Chunk 3)
Goal: Extract calibration, level read, and startup tare state-machine workflows.

Prerequisite:
- Chunk 1 and Chunk 2 are complete and compiling.

IMPORTANT RULES
1) Keep function signatures unchanged where possible.
2) Keep serial message text unchanged.
3) Keep setup() and loop() in PropaneScale.ino for now.
4) Compile after every numbered step.

Current source file:
- PropaneScale/PropaneScale.ino

Suggested destination files:
- PropaneScale/src/workflows/calibration_workflow.h
- PropaneScale/src/workflows/calibration_workflow.cpp
- PropaneScale/src/workflows/level_workflow.h
- PropaneScale/src/workflows/level_workflow.cpp
- PropaneScale/src/workflows/startup_tare_workflow.h
- PropaneScale/src/workflows/startup_tare_workflow.cpp
- PropaneScale/src/workflows/workflow_contexts.h

------------------------------------------------------------
STEP 0 - Baseline compile
------------------------------------------------------------
1) Compile and confirm current baseline.

edits: complete
compile: clean
Sketch uses 315499 bytes (24%)
Global variables use 21000 bytes (6%)
baseline pass

------------------------------------------------------------
STEP 1 - Consolidate workflow type/context declarations
------------------------------------------------------------
Create PropaneScale/src/workflows/workflows_contexts.h and move declarations only:
- CalMode, CalState, CalContext
- LevelState, LevelContext
- TareState, TareContext

For this chunk, keep global storage in PropaneScale.ino:
- CalContext calCtx;
- LevelContext levelCtx;
- TareContext tareCtx;

Add extern declarations in workflow_contexts.h for these globals.
Then in PropaneScale.ino:
1) Include workflow_contexts.h.
2) Remove duplicate enum/struct definitions.
3) Keep global definitions.
4) Compile.

Test Criteria:
Header contains all workflow type declarations
Test: Inspect workflows_contexts.h.
Pass criteria: It declares CalMode, CalState, CalContext, LevelState, LevelContext, TareState, and TareContext.
Fail criteria: Any of these types are missing.

Sketch no longer duplicates moved type declarations
Test: Inspect PropaneScale.ino.
Pass criteria: No local enum/struct declarations for the 7 moved types remain.
Fail criteria: Any duplicate enum/struct still exists in the sketch.

Context globals remain defined in the sketch
Test: Inspect PropaneScale.ino.
Pass criteria: Exactly one definition each for calCtx, levelCtx, and tareCtx exists in the sketch.
Fail criteria: Missing definition, duplicate definition, or moved definition to another file.

Header exposes externs for all three context globals
Test: Inspect workflows_contexts.h.
Pass criteria: extern declarations exist for calCtx, levelCtx, and tareCtx.
Fail criteria: Any extern is missing or type mismatch exists.

Linkage compatibility check for shared globals
Test: Verify definitions in PropaneScale.ino are not static if declared extern in header.
Pass criteria: calCtx/levelCtx/tareCtx definitions use external linkage (no static).
Fail criteria: static is used with matching extern declarations, which breaks cross-TU visibility.

Include wiring is correct
Test: Inspect include list in PropaneScale.ino.
Pass criteria: The contexts header is included once and used by sketch types/variables.
Fail criteria: Missing include, duplicate include confusion, or stale include names.

Header name consistency test
Test: Search project includes for both workflow_contexts.h and workflows_contexts.h.
Pass criteria: One canonical filename is used consistently everywhere.
Fail criteria: Mixed singular/plural header names (high risk of include breakage during extraction steps).

Step gate compile test
Test: Run clean rebuild task ESP32 Thing Clean Rebuild.
Pass criteria: Compile and link succeed with no new type/symbol errors from context migration.
Fail criteria: Any compile/link error related to missing types, duplicate definitions, or undefined context symbols.

EDITS complete
clean compile
Sketch uses 315499 bytes (24%)
Global variables use 21000 bytes (6%)
tests pass

------------------------------------------------------------
STEP 2 - Extract level workflow
------------------------------------------------------------
Create PropaneScale/src/workflows/level_workflow.h declarations:
- void liquidLevel();
- void tickLevelRead();

Create level_workflow.cpp and move exact function bodies:
- liquidLevel
- tickLevelRead

Dependencies in level_workflow.cpp:
- <Arduino.h>
- <math.h>
- <stdio.h>

- "config.h"
- "src/scale_io.h"
- "src/workflows/workflows_contexts.h"

Externs used by this workflow:
- extern float calibrationFactor;
- extern bool ensureScaleReady(const char* operation);
- extern float tankTare;
- extern float maxPropane;

Then in PropaneScale.ino:
1) Include level_workflow.h.
2) Remove moved function bodies.
3) Compile.

Test criteria:
Public API declarations exist in the new level workflow header
Test: Inspect the new header for exactly two declarations: liquidLevel and tickLevelRead.
Pass criteria: Both declarations exist with void return and no parameter changes.
Fail criteria: Missing declaration or signature drift.

Function bodies are moved out of the sketch
Test: Inspect PropaneScale.ino for full definitions of liquidLevel and tickLevelRead.
Pass criteria: Sketch no longer contains those function bodies.
Fail criteria: Either full body still exists in sketch (duplicate definition risk).

Sketch includes the new level workflow header
Test: Inspect include section in PropaneScale.ino.
Pass criteria: New level workflow header is included once.
Fail criteria: Missing include or duplicate/conflicting include.

Moved implementation keeps required dependencies
Test: Inspect the new level workflow source includes.
Pass criteria: It includes Arduino.h, math.h, stdio.h, config.h, scale_io.h, and workflows_contexts.h.
Fail criteria: Missing include causing compile/type errors.

Cross-module globals/functions are declared with extern in the moved source
Test: Inspect new level workflow source for extern declarations used by the moved code.
Pass criteria: calibrationFactor, tankTare, maxPropane, and ensureScaleReady are available without redefining ownership.
Fail criteria: Missing externs, duplicate definitions, or linker errors.

Behavior text and command flow are unchanged
Test: Run the level command path over serial and compare outputs against pre-refactor behavior.
Pass criteria: Same prompts/messages and same cancel/finish behavior.
Fail criteria: Message changes, state timing regressions, or command behavior differences.

No new warnings/errors in compile gate
Test: Run clean rebuild task ESP32 Thing Clean Rebuild.
Pass criteria: Compile/link succeeds with no undefined references or duplicate symbol errors tied to liquidLevel/tickLevelRead.
Fail criteria: Any compile/link failure from extraction.

Functional smoke test for level read workflow
Test: On hardware, trigger level read with no tank, then with tank/load, then cancel path.
Pass criteria: WAIT_LOAD, settling, and final read path still execute correctly; cancel returns to idle cleanly.
Fail criteria: Stuck state, incorrect transition, or failure to return to idle.

EDITS complete
clean compile
Sketch uses 315515 bytes (24%)
Global variables use 21000 bytes (6%)
tests pass

------------------------------------------------------------
STEP 2.5 - Extract runtime tare persistence helper
------------------------------------------------------------
Purpose:
- Move the shared runtime tare EEPROM-save helper out of PropaneScale.ino before extracting startup tare and calibration workflows.
- Keep one implementation that both workflow modules can call after scale.tare().

Preconditions:
- Chunk 1 Step 2 EEPROM module is already complete so saveToEeprom() is available.
- Chunk 1 Step 3 scale I/O module is already complete so the helper can live beside other HX711-related helpers.

Run order (do not skip):
1) Add a declaration to PropaneScale/src/scale_io.h.
	- void saveRuntimeTareOffset();

2) In PropaneScale/src/scale_io.cpp add the needed include and move the exact helper body:
	Required include:
	- #include "eeprom_store.h"
	Move exact body only:
	- saveRuntimeTareOffset
	Required external linkage remains:
	- extern HX711 scale;

3) Update PropaneScale.ino.
	- Remove the local static saveRuntimeTareOffset() definition.
	- Keep existing call sites unchanged.

4) Compile gate.
	Pass if compile succeeds with no undefined references or duplicate symbol errors tied to saveRuntimeTareOffset.

5) Focused runtime gate.
	Test A - runtime re-zero:
	- Send: r
	- Pass if the normal re-zero flow still completes and subsequent reboot behavior reflects the saved runtime tare offset.
	Test B - startup tare persistence:
	- Boot with an empty scale so startup tare succeeds.
	- Pass if startup tare still completes and later reads behave the same as before.

Step 2.5 acceptance criteria:
- Compile passes.
- No user-visible message text changes.
- One shared implementation is used by both startup tare and calibration/re-zero paths.

------------------------------------------------------------
STEP 3 - Extract startup tare workflow
------------------------------------------------------------
Create PropaneScale/src/workflows/startup_tare_workflow.h declarations:
- void beginTare();
- void tickTare();

Create startup_tare_workflow.cpp and move exact function bodies:
- beginTare
- tickTare

Dependencies in startup_tare_workflow.cpp:
- <Arduino.h>
- <math.h>
- <stdio.h>
- "config.h"
- "src/scale_io.h"
- "src/workflows/workflow_contexts.h"

Externs used by this workflow:
- extern float calibrationFactor;
- extern void helpMenu();
- extern void printStartupSummary();  (or keep summary in same module; pick one and stay consistent)

Then in PropaneScale.ino:
1) Include startup_tare_workflow.h.
2) Remove moved function bodies.
3) Compile.

test criteria:
Startup auto-tare success path
Power on with the scale in its expected empty condition.
Pass: startup tare begins automatically, detects stable empty scale, applies tare, and continues to normal operation without user intervention.

Startup skip path
Power on with weight on scale (causes the startup tare wait state), then send the skip input (q) if your workflow supports it.
Pass: startup tare exits cleanly and system proceeds to the same post-startup state as before the refactor.

Startup timeout path
Power on with the scale not meeting the empty/stable condition and do not send input.
Pass: workflow times out exactly as before, prints the same timeout/skip guidance, and returns control without hanging.

Unstable scale path
Power on while the scale reading is noisy or changing.
Pass: startup tare stays in the waiting logic until stable, skipped, or timed out; it does not falsely tare during unstable readings.

HX711 not-ready path
Start with HX711 disconnected, unpowered, or otherwise not ready.
Pass: workflow reports the same diagnostics/cancel behavior as before and does not lock up.

Post-tare normal operation
After a successful startup tare, run a normal command such as level read or another existing serial command.
Pass: system behaves normally, confirming startup tare left state cleanly initialized.

Reboot repeatability
Power cycle and repeat startup tare multiple times under the same empty-scale setup.
Pass: behavior is consistent across runs, with no intermittent stuck state or missed transition.

Message parity check
Compare serial output during success, skip, and timeout runs against pre-refactor behavior.
Pass: user-visible prompts and results are unchanged unless you intentionally modified them.

EDITS complete
clean compile
Sketch uses 317059 bytes (24%)
Global variables use 21000 bytes (6%)
tests pass

------------------------------------------------------------
STEP 4 - Extract calibration workflow
------------------------------------------------------------
Create PropaneScale/src/workflows/calibration_workflow.h declarations:
- void automaticCalibration();
- void handleCalibrationInput(char serialchar);
- void manualCalibration();
- void reZero();
- void tickCalibration();

Create calibration_workflow.cpp and move exact function bodies:
- automaticCalibration
- handleCalibrationInput
- manualCalibration
- reZero
- tickCalibration
- transitionFromWaitEmpty (keep internal static in .cpp)

Dependencies in calibration_workflow.cpp:
- <Arduino.h>
- <math.h>
- <stdio.h>

- "config.h"
- "src/eeprom_store.h"
- "src/scale_io.h"
- "src/workflows/workflow_contexts.h"

Externs commonly needed:
- extern float calibrationFactor;
- extern float knownWeight;
- extern const char* CALIBRATION_SAVE_FAILURE_MSG;
- extern const char* CALIBRATION_SAVE_SUCCESS_MSG;

Then in PropaneScale.ino:
1) Include calibration_workflow.h.
2) Remove moved function bodies.
3) Compile.

test criteria:
1. Automatic Calibration Flow

Start with the scale empty.
Send the command to begin automatic calibration (e.g., a).
Confirm prompts: “Automatic calibration mode”, “Remove all weight from scale”, “Auto-detect is active”, etc.
Place the known calibration weight when prompted.
Confirm: “Weight detected. Settling for ... seconds before measuring...”
Wait for completion.
Confirm: “Automatic calibration complete, computed calibration factor: ...”, “Calibration saved to EEPROM.”
Power cycle and send e to verify the calibration factor persisted.

pass

2. Manual Calibration Flow

Start with the scale empty.
Send the command to begin manual calibration (e.g., m).
Confirm prompts: “Manual calibration mode”, “Remove all weight from scale”, etc.
Place the known calibration weight when prompted.
Use + and - to adjust the calibration factor; confirm the reading and factor update in the output.
Use s to save; confirm: “Manual calibration complete, computed calibration factor: ...”, “Calibration saved to EEPROM.”
Power cycle and send e to verify the calibration factor persisted.

 pass
3. Re-zero Flow

Start with the scale empty.
Send the command to begin re-zero (e.g., r).
Confirm prompts: “Runtime re-zero requested”, “Remove all weight from scale”, etc.
Wait for auto-confirm or send z to force.
Confirm: “Scale re-zero complete.”
Power cycle and verify the tare offset is applied (e.g., by reading a known empty value).

pass

4. Cancel Behavior

Start any calibration workflow (a, m, or r).
While in WAIT_EMPTY or WAIT_LOAD, send q.
Confirm: “Automatic calibration cancelled.” or “Manual calibration cancelled. Changes were not saved.” or “Runtime re-zero cancelled.”
Confirm state returns to idle and no calibration/tare values are changed.

pass

5. Timeout and Error Handling

Start a calibration workflow and do not interact (leave scale non-empty or do not place weight).
Wait for timeout.
Confirm: “Confirmation timed out: scale not empty; cancelled.” or “Weight placement timed out; calibration cancelled.”
Confirm state returns to idle.

pass
pass

6. Invalid Key Handling

During WAIT_EMPTY or WAIT_LOAD, send an invalid key (not q, z, +, -, or s).
Confirm: “Invalid ... calibration key: ...” message appears and workflow continues.

pass

7. Persistence and Consistency

After any calibration, power cycle and verify with e that the calibration factor is correct.
Repeat calibration and re-zero multiple times to confirm no stuck states or missed transitions.

pass

EDITS complete
clean compile
Sketch uses 317175 bytes (24%)
Global variables use 21000 bytes (6%)
tests pass

------------------------------------------------------------
STEP 5 - Cross-workflow command sanity
------------------------------------------------------------
1) Verify these still work:
- a, m, r flows and cancel behavior
- l flow and cancel behavior
- startup tare auto/skip behavior

pass

2) Compile after tests.

clean compile
Sketch uses 317175 bytes (24%)
Global variables use 21000 bytes (6%)
tests pass

------------------------------------------------------------
Expected result after Chunk 3
------------------------------------------------------------
1) All state-machine workflow logic moved out of PropaneScale.ino.
2) PropaneScale.ino now mostly contains setup/loop and utility/output functions.
3) Runtime behavior preserved.

------------------------------------------------------------
Common failure points
------------------------------------------------------------
1) Missing extern for globals used by extracted workflows.
2) Missing include for context enums after moving declarations.
3) Internal static helper moved but still referenced from old file.
4) Circular include from workflow headers; keep headers minimal.

End of Chunk 3 guide.

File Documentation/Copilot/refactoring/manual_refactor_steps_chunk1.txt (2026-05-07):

ESP32 PropaneScale Manual Refactor Guide (Chunk 1)
Goal: Extract low-risk helper and service functions out of PropaneScale.ino without changing behavior.

IMPORTANT RULES
1) Do not change any function signatures in this chunk.
2) Do not change serial message text in this chunk.
3) Compile after every numbered step.
4) If compile fails, revert only the most recent step.

Current source file:
- PropaneScale/PropaneScale.ino

Suggested destination files for this chunk:
- PropaneScale/src/parsing_utils.h
- PropaneScale/src/parsing_utils.cpp
- PropaneScale/src/eeprom_store.h
- PropaneScale/src/eeprom_store.cpp
- PropaneScale/src/scale_io.h
- PropaneScale/src/scale_io.cpp

------------------------------------------------------------
STEP 0 - Baseline compile
------------------------------------------------------------
Purpose:
- Capture known-good behavior before Chunk 1 extraction.
- Use this exact checklist as the comparison baseline after each refactor step.

Preconditions:
- Board connected and powered.
- Serial monitor at 115200.
- Known calibration weight available (26.0 lbs).

Run order (do not skip):
1) Compile and record size.
  Pass if compile succeeds and prints both lines:
  - Sketch uses ... bytes
  - Global variables use ... bytes

2) Upload and boot smoke test.
  Pass if startup output includes app banner/help and no reset loop.
  PASS

3) EEPROM reset baseline.
  Send: d
  Pass if output includes all snippets:
  - Resetting EEPROM to hardcoded defaults...
  - Calibration factor reset to: -10420.86
  - Known calibration weight reset to: 26.00 lbs
  - Max propane weight reset to: 16.00 lbs
  - Tank tare reset to: 17.50 lbs
  - EEPROM reset complete. Recalibrate before use.
  Pass

4) Runtime re-zero baseline.
  Send: r
  Pass if output includes all snippets in order:
  - Runtime re-zero requested.
  - Remove all weight from scale.
  - Auto-detect is active.
  - Send 'q' to cancel.
  - Empty scale auto-detected, continuing with calibration.
  - Scale re-zero complete.
    Pass
    
5) Automatic calibration baseline.
  Send: a
  Keep scale empty until prompted, then place 26.0 lb weight.
  Pass if output includes key snippets:
  - Automatic calibration mode
  - Empty scale confirmed. Taring now...
  - Place the known weight on the scale: 26.00 lbs
  - Waiting for weight placement on scale...
  - Weight detected. Settling for ... seconds before measuring...
  - Measuring stable reading...
  - Automatic calibration complete, computed calibration factor: ...
  - Calibration saved to EEPROM.
  Fail if timeout appears:
  - Weight placement timed out; calibration cancelled.
    Pass
    
6) EEPROM readback baseline.
  Send: e
  Pass if output prints all fields and numeric values:
  - Calibration factor: ...
  - Known calibration weight: ... lbs
  - Max propane weight: ... lbs
  - Tank tare: ... lbs
    PASS
    
7) Level read baseline.
  Send: l, then place tank.
  Pass if output includes:
  - Place propane tank on scale.
  - Waiting for tank placement...
  - Tank detected. Settling for ... seconds before final read...
  - Reading tank weight...
  - Scale load: ... lbs, Calculated propane: ... lbs, Propane level: ...%
    Pass
    
8) Timeout and cancel behavior baseline.
  Start: l and do not place tank.
  Pass if timeout output appears and prompt remains responsive:
  - Tank placement timed out; cancelled.
  Then send: h
  Pass if help menu prints normally.
  PASS

Record this baseline data (copy values):
- Compile: Sketch uses 314963 bytes, Global variables use 21000 bytes
- Calibration factor after auto-cal: -10417.32
- EEPROM values (e): cal=-10417.32 known=26.00 max=16.00 tare=17.50
- One level output line: Scale load=26.0 propane=8.2 level=51.1

Baseline acceptance criteria:
- All 8 run-order checks pass.
- No crashes, hangs, WDT resets, or serial lockups.
- Message text for key workflow lines matches snippets above.

EDITS COMPLETED
CLEAN Compile
TEST SUCCESFUL

------------------------------------------------------------
STEP 1 - Create parsing module
------------------------------------------------------------
Purpose:
- Extract pure parsing/validation helpers with zero runtime behavior changes.

Preconditions:
- Step 0 baseline completed and recorded.
- Working tree clean enough to isolate this step's diffs.

Run order (do not skip):
1) Create PropaneScale/src/parsing_utils.h.
  Required declarations:
  - bool isValidBoundedFloat(float value, float minimumValue, float maximumValue, bool useAbsoluteMagnitude = false);
  - bool parseNonNegativeFloat(const char* text, float& outValue);
  Pass if header has include guard or #pragma once and declarations match exactly.

2) Create PropaneScale/src/parsing_utils.cpp.
  Required includes:
  - #include <math.h>
  - #include <stdlib.h>
  - #include "parsing_utils.h"
  Move exact bodies only:
  - isValidBoundedFloat
  - parseNonNegativeFloat
  Pass if moved functions compile from the new file with unchanged signatures.

3) Update PropaneScale.ino.
  - Add #include "src/parsing_utils.h"
  - Remove the two moved function bodies
  Pass if no duplicate symbol or missing symbol errors.

4) Compile gate.
  Pass if compile succeeds and prints:
  - Sketch uses ... bytes
  - Global variables use ... bytes

5) Quick runtime gate (no full regression yet).
  Send: k
  Enter: 26.0
  Send: s
  Pass if prompt path still works and save/cancel messages are normal.

Step 1 acceptance criteria:
- Compile passes.
- No message text changes observed in quick runtime gate.
- Build size delta is small and explainable.

EDITS COMPLETED
CLEAN Compile
TEST SUCCESFUL

------------------------------------------------------------
STEP 2 - Create EEPROM module
------------------------------------------------------------
Purpose:
- Extract EEPROM persistence and display helpers without changing save/load semantics.

Preconditions:
- Step 1 complete and green.

Run order (do not skip):
1) Create PropaneScale/src/eeprom_store.h.
  Required declarations:
  - bool loadFromEeprom(float& value, uint32_t magicAddr, uint32_t magicValue, uint32_t valueAddr);
  - bool saveToEeprom(float value, uint32_t magic, int magicAddr, int valueAddr);
  - bool printEepromField(const char* label, uint32_t magicAddr, uint32_t magicValue, uint32_t valueAddr, float minValue, float maxValue, bool useAbsMag = false, const char* unitSuffix = nullptr);

2) Create PropaneScale/src/eeprom_store.cpp.
  Required includes:
  - #include <EEPROM.h>
  - #include <Arduino.h>
  - #include "config.h"
  - #include "parsing_utils.h"
  - #include "eeprom_store.h"
  Required external linkage:
  - extern bool eepromReady;
  Move exact bodies only:
  - loadFromEeprom
  - saveToEeprom
  - printEepromField

3) Update PropaneScale.ino.
  - Add #include "src/eeprom_store.h"
  - Remove moved function bodies
  Pass if no unresolved externals and no duplicate definitions.

4) Compile gate.
  Pass if compile succeeds and prints size lines.

5) Runtime EEPROM gate.
  Send: d
  Expected output snippets:
  - Resetting EEPROM to hardcoded defaults...
  - EEPROM reset complete. Recalibrate before use.
  Send: e
  Expected output snippets:
  - Calibration factor: ...
  - Known calibration weight: ... lbs
  - Max propane weight: ... lbs
  - Tank tare: ... lbs
  Power cycle, send: e again.
  Pass if values persist across reboot.

Step 2 acceptance criteria:
- Compile passes.
- d/e behavior and text unchanged.
- EEPROM values persist after reboot.

EDITS COMPLETED
CLEAN Compile
TEST SUCCESFUL

------------------------------------------------------------
STEP 3 - Create scale I/O module
------------------------------------------------------------
Purpose:
- Extract HX711 I/O helpers while preserving timing, readiness checks, and serial behavior.

Preconditions:
- Step 2 complete and green.

Run order (do not skip):
1) Create PropaneScale/src/scale_io.h.
  Required declarations:
  - float readAveragedUnits(int readings, int samplesPerReading);
  - float computeLoadDetectThreshold(float minimumThresholdLbs);
  - bool ensureScaleReady(const char* operation);
  - void flushSerialInput();

2) Create PropaneScale/src/scale_io.cpp.
  Required includes:
  - #include <Arduino.h>
  - #include <math.h>
  - #include "HX711.h"
  - #include "config.h"
  - #include "scale_io.h"
  Required external linkage:
  - extern HX711 scale;
  Move exact bodies only:
  - readAveragedUnits
  - computeLoadDetectThreshold
  - ensureScaleReady
  - flushSerialInput

3) Update PropaneScale.ino.
  - Add #include "src/scale_io.h"
  - Remove moved function bodies

4) Compile gate.
  Pass if compile succeeds and prints size lines.

5) Runtime behavior gate (strict subset of Step 0).
  Test A - serial flush:
  - Type junk keys, then send c
  - Pass if calibration prompt is clean and not polluted by previous input.
  Test B - ensureScaleReady:
  - Temporarily disconnect HX711 data/clock, reboot
  - Pass if output includes HX711 not ready... and workflow exits without hang.
  Test C - load detect:
  - Run a or l and place weight/tank
  - Pass if detection occurs before timeout under normal conditions.

Step 3 acceptance criteria:
- Compile passes.
- Tests A/B/C pass with unchanged message text.
- Pass/fail behavior matches Step 0 baseline.

EDITS COMPLETED
CLEAN Compile
Sketch uses 315419 bytes (24%)
Global variables use 21000 bytes (6%)
TEST Pass

------------------------------------------------------------
STEP 4 - Include cleanup and order checks
------------------------------------------------------------
Purpose:
- Remove dead includes only when proven unused, with zero functional changes.

Preconditions:
- Step 3 complete and green.

Run order (do not skip):
1) Identify includes in PropaneScale.ino no longer needed after extraction.
2) Remove one include at a time.
3) Compile after each removal.
  Pass only if compile remains clean.
4) Stop when the next removal causes any missing symbol/build break.
  Restore the last removed include and continue.

Step 4 acceptance criteria:
- Final compile is clean.
- No runtime logic or messages changed.
- Only include-list diffs in this step.

EDITS complete
CLEAN compile
Sketch uses 315419 bytes (24%)
Global variables use 21000 bytes (6%)
TESTS PASS

------------------------------------------------------------
STEP 5 - Runtime sanity checks over serial
------------------------------------------------------------
Purpose:
- Confirm end-to-end command workflows still match baseline after Chunk 1 extraction.

Preconditions:
- Steps 1-4 complete and green.

Run order (do not skip):
1) Boot sanity.
  Pass if startup summary/help path appears and no reset loop occurs.

2) Command matrix.
  Send commands in this exact order:
  - h
  - e
  - c
  - l then q
  - k then q
  - p then q
  - t then q

3) Expected output snippets by command.
  h:
  - Send 'h' to display this help menu
  e:
  - Calibration factor:
  - Known calibration weight:
  - Max propane weight:
  - Tank tare:
  l then q:
  - Waiting for tank placement...
  - Send 'q' to cancel.
  - Level read cancelled.
  k/p/t then q:
  - After entry, send 's' to save or 'q' to cancel.
  - ... cancelled (for that workflow)

4) Non-regression checks.
  Pass if all are true:
  - No command hangs.
  - No unexpected reboots.
  - No changed wording in key status lines.

5) Final compile confirmation.
  Compile once more and record size.
  Pass if compile succeeds and size remains close to Step 0 baseline.

Step 5 acceptance criteria:
- Full command matrix passes.
- Key message text unchanged.
- Final compile clean.

EDITS complete
CLEAN compile
Sketch uses 315419 bytes (24%)
Global variables use 21000 bytes (6%)
TESTS PASS

------------------------------------------------------------
Expected result after Chunk 1
------------------------------------------------------------
1) PropaneScale.ino is shorter and easier to scan.
2) No workflow behavior changes.
3) setup() and loop() still in PropaneScale.ino.
4) Build output remains close to baseline.

------------------------------------------------------------
If something fails
------------------------------------------------------------
1) Revert only the latest step.
2) Rebuild.
3) Check for one of these common issues:
- Missing #include in new .cpp
- Function still declared static in .ino but moved out
- Missing extern for scale or eepromReady
- Header declaration signature mismatch with .cpp
- Default argument specified in both .h and .cpp (keep default only in .h)

End of Chunk 1 guide.

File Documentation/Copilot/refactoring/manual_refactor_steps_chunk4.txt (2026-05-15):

ESP32 PropaneScale Manual Refactor Guide (Chunk 4)
Goal: Finish cleanup so PropaneScale.ino becomes a thin entry file with orchestration only.

Prerequisite:
- Chunk 1, 2, and 3 are complete and compiling.

IMPORTANT RULES
1) No behavior changes in this chunk.
2) Keep setup() and loop() function names and semantics.
3) Compile after every numbered step.

Current source file:
- PropaneScale/PropaneScale.ino

Suggested additional files:
- PropaneScale/src/app_startup.h
- PropaneScale/src/app_startup.cpp
- PropaneScale/src/commands.h
- PropaneScale/src/commands.cpp
- PropaneScale/src/runtime_report.h
- PropaneScale/src/runtime_report.cpp

------------------------------------------------------------
STEP 0 - Baseline compile
------------------------------------------------------------
1) Compile and confirm baseline after Chunk 3.

EDITS complete
clean compile
Sketch uses 317223 bytes (24%)
Global variables use 21000 bytes (6%)
tests pass
------------------------------------------------------------
STEP 1 - Extract startup summary and runtime reporting
------------------------------------------------------------
Create runtime_report.h declarations:
- void currentRuntimeValues();
- void eepromValues();
- void helpMenu();
- void printStartupSummary();

Create runtime_report.cpp and move exact bodies for those functions.
Dependencies:
- <Arduino.h>
- <stdio.h>
- "config.h"
- relevant workflow/context headers
- "src/eeprom_store.h"

Then in PropaneScale.ino:
1) Include runtime_report.h.
2) Remove moved function bodies.
3) Compile.

edits complete
clean compile
Sketch uses 317219 bytes (24%) of program storage space. Maximum is 1310720 bytes.
Global variables use 21000 bytes (6%) of dynamic memory, leaving 306680 bytes for local variables. Maximum is 327680 bytes.
tests pass

------------------------------------------------------------
STEP 2 - Extract EEPROM reset command implementation
------------------------------------------------------------
Create commands.h declaration:
- void defaultEeprom();

Create commands.cpp and move exact body for defaultEeprom.
Dependencies:
- <Arduino.h>
- "config.h"
- "src/eeprom_store.h"

Then in PropaneScale.ino:
1) Include commands.h.
2) Remove moved body.
3) Compile.

edits complete
clean compile
Sketch uses 317207 bytes (24%) of program storage space. Maximum is 1310720 bytes.
Global variables use 21000 bytes (6%) of dynamic memory, leaving 306680 bytes for local variables. Maximum is 327680 bytes.
tests pass

------------------------------------------------------------
STEP 3 - Extract setup initialization helper
------------------------------------------------------------
Create app_startup.h declaration:
- void initializeApp();

Create app_startup.cpp to hold the body that currently exists in setup() except Serial.begin and final beginTare call split as desired.
Recommended pattern:
- setup() stays in PropaneScale.ino and calls:
  Serial.begin(BAUD);
  initializeApp();  ( which contains the guts of current setup, less the Serial.begin(Baud) and beginTare() calls)
  beginTare();

Dependencies in app_startup.cpp:
- <Arduino.h>
- <EEPROM.h>

- "HX711.h"

- "config.h"
- "src/eeprom_store.h"
- "src/runtime_report.h"
- "src/parsing_utils.h"
- "src/workflows/startup_tare_workflow.h"

Then in PropaneScale.ino:
1) Keep setup() thin and call initializeApp().
2) Compile.

edits complete
clean compile
Sketch uses 317255 bytes (24%) of program storage space. Maximum is 1310720 bytes.
Global variables use 21000 bytes (6%) of dynamic memory, leaving 306680 bytes for local variables. Maximum is 327680 bytes.
tests pass

------------------------------------------------------------
STEP 4 - Keep loop as orchestrator only
------------------------------------------------------------
Target loop responsibilities only:
1) tick calls
- tickCalibration
- tickLevelRead
- tickTare
2) serial read and command dispatch
3) no workflow internals in loop

If any workflow logic still remains in loop besides dispatch checks, move it now into appropriate modules.
Compile.

edits complete
clean compile
Sketch uses 317291 bytes (24%) of program storage space. Maximum is 1310720 bytes.
Global variables use 21000 bytes (6%) of dynamic memory, leaving 306680 bytes for local variables. Maximum is 327680 bytes.
tests pass

------------------------------------------------------------
STEP 5 - Final include and dependency cleanup
------------------------------------------------------------
1) Remove no-longer-used includes from PropaneScale.ino.
2) Keep module includes grouped and minimal.
3) Verify no duplicate function definitions remain.
4) Compile.

------------------------------------------------------------
STEP 6 - Final validation pass
------------------------------------------------------------
1) Exercise full command set:
- h, c, e, d
- a, m, r
- l
- k, p, t
2) Verify startup tare behavior.
3) Verify no serial message regressions.
4) Confirm flash/RAM are in expected range.

edits complete
clean compile
Sketch uses 317291 bytes (24%) of program storage space. Maximum is 1310720 bytes.
Global variables use 21000 bytes (6%) of dynamic memory, leaving 306680 bytes for local variables. Maximum is 327680 bytes.
tests pass

------------------------------------------------------------
Expected end-state
------------------------------------------------------------
1) PropaneScale.ino is a thin entry/orchestration file.
2) Workflows live under src/workflows.
3) Helpers/services live under src.
4) Manual navigation/readability is significantly improved.

------------------------------------------------------------
Optional next improvement after Chunk 4
------------------------------------------------------------
1) Replace extern globals with a single AppState struct passed by reference.
2) This reduces hidden coupling and makes unit testing easier.
3) Do this only after behavior is stable post-refactor.

End of Chunk 4 guide.

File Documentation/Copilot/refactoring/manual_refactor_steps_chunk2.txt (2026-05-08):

ESP32 PropaneScale Manual Refactor Guide (Chunk 2)
Goal: Extract serial input workflows to dedicated files while keeping command routing in PropaneScale.ino.

Prerequisite:
- Chunk 1 is complete and compiling.

IMPORTANT RULES
1) Keep all function signatures unchanged.
2) Keep all serial messages unchanged.
3) Do not change command behavior in loop().
4) Compile after every numbered step.

Current source file:
- PropaneScale/PropaneScale.ino

Suggested destination files:
- PropaneScale/src/workflows/input_known_weight.h
- PropaneScale/src/workflows/input_known_weight.cpp
- PropaneScale/src/workflows/input_propane_weight.h
- PropaneScale/src/workflows/input_propane_weight.cpp
- PropaneScale/src/workflows/input_tank_tare.h
- PropaneScale/src/workflows/input_tank_tare.cpp
- PropaneScale/src/workflows/input_context.h

------------------------------------------------------------
STEP 0 - Baseline compile
------------------------------------------------------------
1) Compile before starting and confirm success.

CLEAN COMPILE
Sketch uses 315419 bytes (24%)
Global variables use 21000 bytes (6%)
SAME as Chunk1 final

------------------------------------------------------------
STEP 1 - Create shared input context header
------------------------------------------------------------
Create PropaneScale/src/workflows/input_context.h and move declarations only:
- enum class InputMode
- enum class InputState
- struct InputContext

For chunk 2, keep global storage in PropaneScale.ino:
- static InputContext inputCtx;

In input_context.h, add extern declaration:
- extern InputContext inputCtx;

Then in PropaneScale.ino:
1) Include "src/workflows/input_context.h".
2) Remove duplicate enum/struct definitions from PropaneScale.ino.
3) Keep the single global definition: InputContext inputCtx.
4) Compile.

Test Criteria:
No duplicate definition errors for InputMode, InputState, or InputContext.
No missing type errors for uint8_t.
No multiple-definition error for inputCtx.

EDITS complete
CLEAN Compile
Sketch uses 315419 bytes (24%)
Global variables use 21000 bytes (6%)
TESTS Pass

------------------------------------------------------------
STEP 2 - Extract known weight workflow
------------------------------------------------------------
Create input_known_weight.h declarations:
- void knownWeightUpdate();
- void handleKnownWeightInput(char incoming);

Create input_known_weight.cpp and move exact function bodies:
- knownWeightUpdate
- handleKnownWeightInput

Dependencies to include in input_known_weight.cpp:
- <Arduino.h>
- <math.h>
- <stdio.h>
- "config.h"
- "src/workflows/input_context.h"
- "src/parsing_utils.h"
- "src/eeprom_store.h"
- "src/scale_io.h"  (for flushSerialInput)

For chunk 2, use extern declarations for globals used by these functions:
- extern float knownWeight;
- extern void resetInputContext();

Then in PropaneScale.ino:
1) Add include for input_known_weight.h.
2) Remove moved function bodies.
3) Compile.

Test Criteria:
Send h and verify the k command still appears in help.
Send k and verify the prompt text is unchanged.
Enter a valid value like 26 and confirm the save/cancel prompt appears exactly as before.
Send s and verify knownWeight updates and persists.
Run e or c and confirm the updated value is shown.
Repeat with q and verify cancellation leaves the old value unchanged.
Repeat with invalid input like negative text or out-of-range value and confirm the rejection message is unchanged.

EDITS complete
TESTS pass
Clean Compile
Sketch uses 315447 bytes (24%)
Global variables use 21000 bytes (6%)

------------------------------------------------------------
STEP 3 - Extract max propane workflow
------------------------------------------------------------
Create input_propane_weight.h declarations:
- void handlePropaneWeightInput(char incoming);
- void propaneWeightUpdate();

Create input_propane_weight.cpp and move exact function bodies:
- handlePropaneWeightInput
- propaneWeightUpdate

Dependencies to include in input_propane_weight.cpp:
- <Arduino.h>
- <math.h>
- <stdio.h>

- "config.h"
- "src/eeprom_store.h"
- "src/parsing_utils.h"
- "src/scale_io.h"
- "src/workflows/input_context.h"

Externs for chunk 2:
- extern float maxPropane;
- extern void resetInputContext();

Then in PropaneScale.ino:
1) Add include for input_propane_weight.h.
2) Remove moved function bodies.
3) Compile.

Test Criteria:
Send p and verify the prompt is unchanged.
Enter a valid value like 16 and send s.
Verify with e or c that maxPropane changed.
Repeat with q and verify the previous value remains.
Repeat with invalid input and confirm the rejection path is unchanged.

EDITS COMPLETE
Tests pass
clean compile
Sketch uses 315471 bytes (24%)
Global variables use 21000 bytes (6%)

------------------------------------------------------------
STEP 4 - Extract tank tare workflow
------------------------------------------------------------
Create input_tank_tare.h declarations:
- void handleTankTareInput(char incoming);
- void tankTareUpdate();

Create input_tank_tare.cpp and move exact function bodies:
- handleTankTareInput
- tankTareUpdate

Dependencies to include in input_tank_tare.cpp:
- <Arduino.h>
- <math.h>
- <stdio.h>

- "config.h"
- "src/eeprom_store.h"
- "src/parsing_utils.h"
- "src/scale_io.h"
- "src/workflows/input_context.h"

Externs for chunk 2:
- extern void resetInputContext();
- extern float tankTare;

Then in PropaneScale.ino:
1) Add include for input_tank_tare.h.
2) Remove moved function bodies.
3) Compile.

Test Criteria:
Send t and verify the prompt is unchanged.
Enter a valid tare like 17.5 and send s.
Verify with e or c that tankTare changed.
Repeat with q and verify cancel behavior.
Repeat with invalid input and confirm rejection behavior is unchanged.

edits complete
clean compile
Sketch uses 315499 bytes (24%)
Global variables use 21000 bytes (6%)
tests pass

------------------------------------------------------------
STEP 5 - Keep loop routing unchanged
------------------------------------------------------------
1) Verify loop() still routes exactly as before:
- InputMode::TANK_TARE -> handleTankTareInput
- InputMode::PROPANE_WEIGHT -> handlePropaneWeightInput
- InputMode::KNOWN_WEIGHT -> handleKnownWeightInput
2) Compile.

Test Criteria:
Send k and make sure only the known-weight workflow starts.
Send p and make sure only the propane-weight workflow starts.
Send t and make sure only the tank-tare workflow starts.
While one workflow is active, send unrelated characters and verify they do not jump into another workflow.

edits: complete
compile: clean
Sketch uses 315499 bytes (24%)
Global variables use 21000 bytes (6%)
tests pass

------------------------------------------------------------
STEP 6 - Serial behavior sanity check
------------------------------------------------------------
1) Test command flows manually:
- k then numeric entry then s/q
- p then numeric entry then s/q
- t then numeric entry then s/q
2) Confirm prompts and warnings match previous behavior exactly.

Test Criteria:
k → valid number → s
p → valid number → s
t → valid number → s
Then reboot the board and run e.
Pass criteria:
All three saved values persist across reboot.
Prompt text and warning text match pre-refactor behavior.
No workflow gets stuck in WAIT_SAVE_CONFIRM or leaves inputCtx in a bad state.

edits: complete
compile: clean
Sketch uses 315499 bytes (24%)
Global variables use 21000 bytes (6%)
tests pass

------------------------------------------------------------
Expected result after Chunk 2
------------------------------------------------------------
1) All three input workflows are out of PropaneScale.ino.
2) loop() dispatch remains simple and unchanged.
3) Behavior remains identical.

Test Criteria:
Missing externs for resetInputContext or the data globals.
Loop routing still calling old handlers or wrong handlers.
Save works but cancel no longer restores prior state.
Prompt text changes accidentally during extraction.

------------------------------------------------------------
Common failure points
------------------------------------------------------------
1) Missing include for InputMode/InputState/InputContext.
2) Missing extern for resetInputContext or data globals.
3) Header signature mismatch vs implementation.
4) Default arguments duplicated in both .h and .cpp (default only in .h).

End of Chunk 2 guide.

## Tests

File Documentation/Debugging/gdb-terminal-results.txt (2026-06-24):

PS C:\Users\gmanw> & "C:\Users\gmanw\AppData\Local\Arduino15\packages\esp32\tools\xtensa-esp-elf-gdb\16.3_20250913\bin\xtensa-esp32-elf-gdb.exe" D:\MyArduino\Projects\ESP32_Scale\PropaneScale\build\esp32.esp32.esp32thing\PropaneScale.ino.elf
GNU gdb (esp-gdb) 16.3_20250913
Copyright (C) 2024 Free Software Foundation, Inc.
License GPLv3+: GNU GPL version 3 or later <http://gnu.org/licenses/gpl.html>
This is free software: you are free to change and redistribute it.
There is NO WARRANTY, to the extent permitted by law.
Type "show copying" and "show warranty" for details.
This GDB was configured as "--host=x86_64-w64-mingw32 --target=xtensa-esp-elf".
Type "show configuration" for configuration details.
For bug reporting instructions, please see:
<https://www.gnu.org/software/gdb/bugs/>.
Find the GDB manual and other documentation resources online at:
    <http://www.gnu.org/software/gdb/documentation/>.

For help, type "help".
Type "apropos word" to search for commands related to "word"...
Reading symbols from D:\MyArduino\Projects\ESP32_Scale\PropaneScale\build\esp32.esp32.esp32thing\PropaneScale.ino.elf...

after connection to openocd:
(gdb) target extended-remote :3333
Remote debugging using :3333
warning: could not convert 'main' from the host encoding (CP1252) to UTF-32.
This normally should not happen, please file a bug report.
0x4008966a in esp_cpu_wait_for_intr () at /home/runner/work/esp32-arduino-lib-builder/esp32-arduino-lib-builder/esp-idf/components/esp_hw_support/cpu.c:64
warning: 64     /home/runner/work/esp32-arduino-lib-builder/esp32-arduino-lib-builder/esp-idf/components/esp_hw_support/cpu.c: No such file or directory
(gdb) monitor halt
(gdb)

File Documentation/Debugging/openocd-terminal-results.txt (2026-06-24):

PS C:\Users\gmanw> openocd -f interface/ftdi/esp32_devkitj_v1.cfg -f target/esp32.cfg -c "init"
xPack Open On-Chip Debugger 0.12.0+dev-02228-ge5888bda3-dirty (2025-10-04-22:44)
Licensed under GNU GPL v2
For bug reports, read
        http://openocd.org/doc/doxygen/bugs.html
Info : [esp32.cpu0] Hardware thread awareness created
Info : [esp32.cpu1] Hardware thread awareness created
force hard breakpoints
Info : clock speed 500 kHz
Info : JTAG tap: esp32.cpu0 tap/device found: 0x120034e5 (mfg: 0x272 (Tensilica), part: 0x2003, ver: 0x1)
Info : JTAG tap: esp32.cpu1 tap/device found: 0x120034e5 (mfg: 0x272 (Tensilica), part: 0x2003, ver: 0x1)
Info : [esp32.cpu0] Examination succeed
Info : [esp32.cpu1] Examination succeed
Info : [esp32.cpu0] starting gdb server on 3333
Info : Listening on port 3333 for gdb connections
Info : Listening on port 6666 for tcl connections
Info : Listening on port 4444 for telnet connections
Info : Set GDB target to 'esp32.cpu0'
Info : [esp32.cpu1] Debug controller was reset.
Info : [esp32.cpu1] Core was reset.

After gdb:
Info : accepting 'gdb' connection on tcp/3333
Info : Set GDB target to 'esp32.cpu0'
Info : New GDB Connection: 1, Target esp32.cpu0, state: halted

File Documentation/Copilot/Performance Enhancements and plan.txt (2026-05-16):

suggest, but do not implement, performance enhancements.

Top performance enhancements to consider next, ranked by impact:

1. Split blocking measurement from async acquisition
Create a true non-blocking HX711 sampler that takes at most one sample per loop tick (is_ready() gated), 
accumulates into a small state object, and reports “done” when target sample count reached.
Biggest gain: keeps loop latency low for serial, future web server, OTA, and watchdog health.

this is:
@todo readAveragedUnits() uses wait_ready_timeout() per iteration so it no longer spins
indefinitely, but it still blocks loop() for up to HX711_READY_TIMEOUT_MS per reading
(e.g. up to ~120ms per call for single-reading polling paths, more for multi-reading measurement calls). 
Acceptable for serial-only use. 
When adding a web interface, refactor
callers to drive one reading per loop() tick via is_ready() and accumulate across ticks.

This is first ticket in web interface refactor.

2. Replace repeated switch-to-string logic in runtime prints with lookup tables
Your enum-name printing is clear, but multiple switch blocks add flash and branch cost.
Use compact const char* tables indexed by enum value for faster, smaller diagnostics paths.

3. Reduce Serial.print fragmentation
Many small prints create UART overhead and timing sensitivity.
Build fewer, larger lines or short buffered chunks for startup summaries and menus to reduce transmit churn and startup jitter.
IMPLEMENTED

4. Make detection thresholds adaptive with hysteresis + debounce windows
Instead of frequent repeated reads plus hard cutoffs, use a filtered signal with hysteresis.
Gains: fewer false transitions, fewer expensive measurement cycles, smoother state flow.

5. Add fast/slow sampling profiles per state
Polling states: minimal samples and short readiness checks.
Final measurement states: larger averages.
You already moved in this direction; formalizing profiles can trim average loop time further.

6. Cache rarely changing computed values
Values like effective tare combinations and threshold multipliers can be precomputed 
when configuration changes instead of recomputed across ticks.
Small but consistent CPU savings.

7. Minimize EEPROM commit frequency and batch writes
Persist only on explicit confirmation boundaries and avoid repeated commit patterns in close succession.
Gains: latency reduction and flash wear reduction.

8. Move high-frequency math to cheaper forms where safe
Replace some float-heavy paths in polling logic with scaled integer comparisons once calibration/units are stable.
Useful on tight loop sections, especially if you add networking.

suggest, but do not implement, performance enhancements predicated on serial monitor usage.
I want to have the project at peak performance for usb connection before I start web interface version.
The Serial monitor usage version will always be usb connected to computer.
This will also be the case when I am developing the web interface version.

Given USB is always connected and the monitor is always active, 
suggestions like CDC detection and compile-time stripping are irrelevant here. 
The relevant ones, reframed for your actual constraint:

9. Baud rate increase — one-liner, immediate gain
Serial.begin(921600) in setup(). 
Since the host is always connected and a terminal is always open, there's no compatibility risk. 
Direct reduction in time Serial.print blocks waiting for the TX FIFO to drain on every call.
Change baud to 921600 and verify your monitor/tooling is stable.

Not worth it. ESP32 reset/boot hard codes in ROM defaults to 115200.
Therefore, will never be able to change it, and setup is 2nd bootloader, which runs AFTER,
so cannot change programatically either.

10. Tick output rate-limiting — highest loop() throughput impact
tickCalibration() and tickLevelRead() can emit a serial write every loop() iteration during SETTLING/READING states. 
A static uint32_t lastPrintMs gate (e.g., 250 ms) collapses dozens of writes per second down to 4, 
with no perceptible difference to a human reading the monitor. 
The HX711 read cadence is the real bottleneck there, not the display rate.

11. Serial.availableForWrite() guard on large prints
The 192-byte warnBuf strings and multi-line calibration prompts can stall loop() if the 256-byte ESP32 UART TX FIFO is already partially full. 
Checking Serial.availableForWrite() >= len before the print keeps the main loop from blocking. 
Low code complexity; directly improves responsiveness during calibration flows.

12. Consolidate per-loop status output into a single structured line
Rather than emitting weight readings as prose ("Weight: 12.34 lbs\n"), 
emit a single fixed-format CSV or JSON line (e.g., W,12.34,45\n). 
One write, smaller payload, faster drain. 
Also directly reusable as the data format for the web interface's WebSocket push
— you won't have to redesign the output format mid-port.

Update:
Priority order for your current situation:

Manual refactor chunks
Why first: this is the biggest enabler. It reduces risk and makes every later performance change easier to implement, test, and roll back.

Sketch uses 317291 bytes (24%) of program storage space. Maximum is 1310720 bytes.
Global variables use 21000 bytes (6%) of dynamic memory, leaving 306680 bytes for local variables. Maximum is 327680 bytes.
COMPLETE

item 1
True non-blocking HX711 sampler: already reserved as first step in web-interface phase, so this ordering avoids conflicting rework before that.
DEFERRED

item 12
Consolidate per-loop status output into a single structured line
Why here: strong payoff now and directly reusable for web telemetry later. It also reduces serial overhead by standardizing to one compact line format.

Not worth it for serial monitor version. Revisit for web interface.
Sketch uses 317291 bytes (24%) of program storage space. Maximum is 1310720 bytes.
Global variables use 21000 bytes (6%) of dynamic memory, leaving 306680 bytes for local variables. Maximum is 327680 bytes.
DEFERRED

item 10
Tick output rate-limiting
Why next: high impact when output is periodic. Apply only to truly repetitive status paths so you keep important event messages immediate.

Empirical testing showed More printing, not less.
DROPPED

item 11
Serial.availableForWrite() guard on large prints
Why after rate limiting: good protection against loop stalls, but mainly useful once high-frequency output is already trimmed.

Sketch uses 317595 bytes (24%) of program storage space. Maximum is 1310720 bytes.
Global variables use 23056 bytes (7%) of dynamic memory, leaving 304624 bytes for local variables. Maximum is 327680 bytes.
 
tests: verify that help, runtime report, and startup prompts still appear in the expected order. PASSED
verify eeprom prints, scale prints, calibration prints, all 3 input prints, level prints appear correctly. PASS
COMPLETED

item 2
Replace repeated switch-to-string logic in runtime prints with lookup tables
Why mid-pack: clean and slightly smaller/faster diagnostics path, but lower impact than serial traffic shaping.
TODO

item 4
Make detection thresholds adaptive with hysteresis + debounce windows
Why later: can improve robustness/noise behavior, but introduces behavior tuning complexity. Better after code is modular and baseline behavior is stable.
TODO

item 5
Add fast/slow sampling profiles per state
Why later: useful, but it overlaps with your planned web-first non-blocking acquisition redesign, so avoid spending too much on pre-redesign tuning.
TODO

item 6
Cache rarely changing computed values
Why low priority: likely micro-gains only in this codebase compared with serial and acquisition flow changes.
TODO

item 7
Minimize EEPROM commit frequency and batch writes
Why dropped: in your current flow, EEPROM writes are already user-driven save events, not high-frequency loop writes. This is not a meaningful runtime performance bottleneck right now.
DROPPED

item 3
Reduce Serial.print fragmentation
COMPLETED

item 9
Baud rate increase: intentionally excluded per your ROM boot visibility requirement.
DROPPED

Update 2:

Priority (High → Low):

High
- Item 1 — Split blocking measurement from async acquisition: Status: Recommended / High priority.
	Action: Implement a non-blocking HX711 sampler with `startSampleBatch(n)`, `pollSample()`, `isSampleDone()`, `getSampleResult()` and update callers in workflows to poll once-per-loop tick. 
  Rationale: required for a responsive web interface and to keep loop latency low; preserve Serial monitor by forwarding structured telemetry lines when debugging.

High‑Medium
- Item 12 — Consolidate per-loop status into a single structured line: Status: Deferred / Recommended for web phase.
	Action: Standardize per-loop output to one-line JSON or compact CSV (e.g., `{"w":12.34,"s":45}`). 
  Use the same format for Serial debug output and WebSocket/HTTP telemetry to avoid format churn during porting.

Medium
- Item 2 — Replace repeated switch-to-string logic with lookup tables: Status: Worth doing / Medium priority.
	Action: Replace enum switch blocks with `const char*` tables indexed by enum values when editing diagnostic/print paths.

- Item 4 — Adaptive thresholds (hysteresis + debounce): Status: Useful later / Medium priority.
	Action: Implement a filtered decision layer with hysteresis windows once the sampling path is non-blocking and stable; this reduces false transitions and expensive cycles.

- Item 5 — Fast/slow sampling profiles per state: Status: Keep / Defer.
	Action: Define lightweight sampling profiles (polling vs final average) and apply them after non-blocking sampler exists.

Medium‑Low
- Item 8 — Move high-frequency math to integer forms: Status: Consider after profiling / Low–Medium priority.
	Action: Replace float-heavy comparisons in hot loops with scaled integer math where safe to reduce CPU cost.

Low
- Item 6 — Cache rarely changing computed values: Status: Low priority / Optional.
	Action: Precompute threshold multipliers and tare combos on config change rather than in every tick.

Dropped / Not applicable
- Item 7 — Minimize EEPROM commit frequency and batch writes: DROPPED (writes are user-driven).
- Item 9 — Baud rate increase: NOT APPLICABLE (ROM/boot constraints prevent safe change).
- Item 10 — Tick output rate-limiting: DROPPED (empirical tests showed no benefit for your flow).

Completed
- Item 3 — Reduce Serial.print fragmentation: COMPLETED.
- Item 11 — `Serial.availableForWrite()` guard: COMPLETED.

Next recommended immediate action: 
implement Item 1 (non-blocking sampler) and add a lightweight `telemetry_write()` helper that emits one-line JSON to both Serial (for debug) and a small web telemetry buffer. 
This gives the largest net improvement for adding a web interface while preserving Serial monitor functionality.

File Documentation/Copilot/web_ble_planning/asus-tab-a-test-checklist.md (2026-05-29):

# Asus Tab A — Web Bluetooth Test Checklist

Purpose: quick, repeatable test steps to validate Web Bluetooth behavior on an Asus Tab A (Android) using Chrome and Firefox.

Prerequisites
- ESP32 running a test firmware exposing service UUID `0000FEED-0000-1000-8000-00805F9B34FB` (or update to match your firmware).
- `nRF Connect` (Android) installed for BLE inspection.
- Test web app hosted over HTTPS (GitHub Pages or local HTTPS). For quick local tests, use a device-hosted `localhost` or a desktop-HTTPS server accessible by the tablet.

Checklist
1. Browser capability
   - Open Chrome on the tablet, navigate to `about:blank`, open DevTools (via remote debugging) or use a page with a console.
   - Run in console:
     ```javascript
     console.log('navigator.bluetooth' in window, navigator.bluetooth !== undefined);
     ```
   - Expect: `true true` in Chrome. If false, try Firefox; if Firefox is false, prefer Chrome.

2. BLE advertisement check (nRF Connect)
   - Open `nRF Connect`, scan, and confirm the ESP32 advertises the expected Service UUID.
   - Inspect advertised characteristics and descriptors for presence of expected UUIDs.

3. Connect via browser (Chrome recommended)
   - Open the hosted Web BLE test page (HTTPS) on the tablet.
   - Click `Connect`, select the device in the chooser (filtered by service UUID if implemented).
   - Verify UI shows `Connected` and the device name.

4. Notifications & streaming
   - Enable notifications for Weight and/or Raw ADC; observe updates.
   - Target update interval: ~100 ms. Verify UI updates at expected rate; measure jitter and latency qualitatively.

5. Control commands
   - Press `Tare` → ensure device acknowledges (weight resets to near zero) and no error is thrown.
   - Send `Calibrate` with a known mass and verify a calibration success path (firmware response or device info change).

6. Disconnect and reconnect
   - Test clean disconnect, and automatic reconnect behavior if implemented.
   - Verify sequence numbers (if present) continue or reset meaningfully.

7. Cross-browser check (optional)
   - Repeat steps 3–6 in Firefox on the tablet and note any differences (API availability, chooser behavior, UUID discovery quirks). Record required flags or version numbers if Firefox needed special config.

8. Record results
   - Note browser name & version, Android version, firmware build, and any flags set.
   - Save logs/screenshots and file them under `Documentation/Copilot/web_ble_planning/logs/`.

Notes
- If the tablet cannot reach an HTTPS host you control, use GitHub Pages for easy HTTPS hosting of the test page.
- If Firefox requires `experimental-web-platform-features` or similar flags, document steps to enable these flags for future reproductions.

Reference
- See `Documentation/Copilot/examples/ble_test_vectors.md` for test payloads and expected hex sequences.

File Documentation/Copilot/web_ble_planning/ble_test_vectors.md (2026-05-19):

# BLE Test Vectors — PropaneScale

This file provides example hex test vectors for each characteristic defined in `firmware/ble_service_spec.md`. Use these with nRF Connect (or similar BLE tool) and as validation inputs for the Web Bluetooth client.

## How to use
- Open nRF Connect (or any BLE explorer).
- Connect to a PropaneScale device advertising service UUID `0000FEED-0000-1000-8000-00805F9B34FB`.
- For notify characteristics (Weight, Raw ADC, Battery), use the "Enable notifications" action and observe incoming packets; compare against these vectors.
- For write characteristics (Tare, Calibrate, Sampling Rate), use the "Write" feature and paste the hex bytes below.

---

## 1) Weight (Notify / Read) — `0000BE01-0000-1000-8000-00805F9B34FB`
Format (9 bytes):
- `uint8 version` (1)
- `int32 weight_mg` (LE)
- `uint16 seq` (LE)
- `int16 reserved`

Example: weight = 1,000 g → weight_mg = 1,000,000 (0x0F4240)
- Payload (hex): `01 40 42 0F 00 01 00 00 00`
  - Breakdown: `01`=version, `40 42 0F 00`=1,000,000 LE, `01 00`=seq=1, `00 00`=reserved

## 2) Tare Command (Write Without Response) — `0000BE02-...`
Format (1 byte):
- `uint8 cmd` (0x01 = TARE_NOW)

Example write (hex): `01`

## 3) Calibrate Command (Write) — `0000BE03-...`
Format (6 bytes):
- `uint8 cmd` (0x01 = CAL_START_SINGLE_WEIGHT)
- `uint32 mass_g` (LE)
- `uint8 options`

Example: calibrate with 500 g
- Payload (hex): `01 F4 01 00 00 00`
  - `01`=cmd, `F4 01 00 00`=500 LE, `00`=options

## 4) Raw ADC (Notify / Read) — `0000BE04-...`
Format (9 bytes):
- `uint8 version` (1)
- `int32 adc_counts` (LE)
- `uint16 seq` (LE)
- `int16 reserved`

Example: adc_counts = 123,456 (0x01E240)
- Payload (hex): `01 40 E2 01 00 01 00 00 00`
  - `01`=version, `40 E2 01 00`=123456 LE, `01 00`=seq=1

## 5) Sampling Rate (Read/Write) — `0000BE05-...`
Format (2 bytes):
- `uint16 interval_ms` (LE)

Example: 100 ms
- Payload (hex): `64 00`

## 6) Battery (Read / Notify) — `0000BE06-...`
Format (3 bytes):
- `uint8 version` (1)
- `uint16 battery_mv` (LE)

Example: 3700 mV
- Payload (hex): `01 74 0E`
  - `0x0E74` = 3700 → LE bytes `74 0E`

## 7) Device Info / Version (Read) — `0000BE07-...`
- UTF-8 text, up to 32 bytes: `manufacturer|model|fw_version|build`
- Example string: `Acme|PropaneScale|v1.2.0|2026-05-19`

---

## Quick Web Bluetooth parse example (weight notification)
Use this as a reference to validate notification parsing in the browser client:

```javascript
function parseWeightNotification(value) {
  // value is a DataView or ArrayBuffer from characteristicvaluechanged
  const dv = new DataView(value);
  const version = dv.getUint8(0);
  const weight_mg = dv.getInt32(1, true); // little-endian
  const seq = dv.getUint16(5, true);
  return { version, weight_mg, seq };
}
```

---

If you want, I can also generate a machine-readable JSON file of these vectors (for automated tests) and add a small Node.js script to replay write vectors via `noble` on a test rig.

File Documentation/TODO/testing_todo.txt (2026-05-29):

1) add mocks for unit testing
2) need local testing
3) need github ci testing

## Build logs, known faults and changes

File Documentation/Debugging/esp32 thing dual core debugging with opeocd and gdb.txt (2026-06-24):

the sparkfun esp32 thing has 2 cores. How do I debug both?

To debug both cores of the ESP32 simultaneously, you take advantage of OpenOCD’s dual-core SMP (Symmetric Multiprocessing) feature. 
OpenOCD has already grouped both cores together behind the scenes under a single GDB server on port 3333.
When you issue commands in GDB, they apply to both cores at once. 
Halting pauses both cores, and continuing resumes both cores.

Here is how to monitor and switch between cpu0 (Protocol/App Core) and cpu1 (Real-time Core Core) inside your active GDB session.

1. View the Status of Both Cores
To see what each core is doing at this exact moment, run the info threads command at your (gdb) prompt:
(gdb) info threads

(gdb) info threads
  Id   Target Id                                                      Frame
* 1    Thread 1 "esp32.cpu0" (Name: esp32.cpu0, state: debug-request) 0x4008966a in esp_cpu_wait_for_intr ()
    at /home/runner/work/esp32-arduino-lib-builder/esp32-arduino-lib-builder/esp-idf/components/esp_hw_support/cpu.c:64
  2    Thread 2 "esp32.cpu1" (Name: esp32.cpu1, state: debug-request) 0x400e1dc3 in WiFiSTAClass::config (this=0x0, local_ip=..., gateway=..., subnet=..., dns1=..., dns2=...)
    at C:\Users\gmanw\AppData\Local\Arduino15\packages\esp32\hardware\esp32\3.3.4\libraries\Network\src/NetworkInterface.h:41
(gdb)

What you will see:GDB maps each ESP32 core to a software "thread." 
It will output a table showing Thread 1 (esp32.cpu0) and Thread 2 (esp32.cpu1) along with their current program counter memory addresses. 
The asterisk * shows which core your current command view is focused on.

2. Switch Your Focus to the Second Core
If you want to inspect variables, local registers, or memory layouts local to Core 1 instead of Core 0, switch your active view using the thread command:
(gdb) thread 2

(gdb) thread 2
[Switching to thread 2 (Thread 2)]
#0  0x400e1dc3 in WiFiSTAClass::config (this=0x0, local_ip=..., gateway=..., subnet=..., dns1=..., dns2=...)
    at C:\Users\gmanw\AppData\Local\Arduino15\packages\esp32\hardware\esp32\3.3.4\libraries\Network\src/NetworkInterface.h:41
warning: Source file is more recent than executable.
41          IPAddress dns1 = (uint32_t)0x00000000, IPAddress dns2 = (uint32_t)0x00000000, IPAddress dns3 = (uint32_t)0x00000000
(gdb)

Note: Type thread 1 to switch back to Core 0.
(gdb) thread 1
[Switching to thread 1 (Thread 1)]
#0  0x4008966a in esp_cpu_wait_for_intr () at /home/runner/work/esp32-arduino-lib-builder/esp32-arduino-lib-builder/esp-idf/components/esp_hw_support/cpu.c:64
warning: 64     /home/runner/work/esp32-arduino-lib-builder/esp32-arduino-lib-builder/esp-idf/components/esp_hw_support/cpu.c: No such file or directory
(gdb)

3. Core-Specific Breakpoints
Because the framework handles the dual-core clustering, when you set a standard breakpoint like break loop, GDB evaluates it hardware-wide. 
Whichever core hits that specific section of code first will trigger the break, automatically halting the companion core at the exact same instant so your data stays synchronized.
If you are running specific background tasks on Core 1 using Arduino's xTaskCreatePinnedToCore(), you can target those background functions directly:
(gdb) break <yourCore1TaskFunction>
(gdb) c

Quick Reference Workflow
Try this exact sequence in your current open GDB window right now:
a) monitor halt (Make sure the chip is paused)
b) info threads (Observe where cpu0 and cpu1 are sitting)
c) thread 2 (Target the second core)
d) where (Print the backtrace stack trace for core 1)

(gdb) monitor halt
(gdb) info threads
  Id   Target Id                                                      Frame
* 1    Thread 1 "esp32.cpu0" (Name: esp32.cpu0, state: debug-request) 0x4008966a in esp_cpu_wait_for_intr ()
    at /home/runner/work/esp32-arduino-lib-builder/esp32-arduino-lib-builder/esp-idf/components/esp_hw_support/cpu.c:64
  2    Thread 2 "esp32.cpu1" (Name: esp32.cpu1, state: debug-request) 0x400e1dc3 in WiFiSTAClass::config (this=0x0, local_ip=..., gateway=..., subnet=..., dns1=..., dns2=...)
    at C:\Users\gmanw\AppData\Local\Arduino15\packages\esp32\hardware\esp32\3.3.4\libraries\Network\src/NetworkInterface.h:41
(gdb) thread 2
[Switching to thread 2 (Thread 2)]
#0  0x400e1dc3 in WiFiSTAClass::config (this=0x0, local_ip=..., gateway=..., subnet=..., dns1=..., dns2=...)
    at C:\Users\gmanw\AppData\Local\Arduino15\packages\esp32\hardware\esp32\3.3.4\libraries\Network\src/NetworkInterface.h:41
41          IPAddress dns1 = (uint32_t)0x00000000, IPAddress dns2 = (uint32_t)0x00000000, IPAddress dns3 = (uint32_t)0x00000000
(gdb) where
#0  0x400e1dc3 in WiFiSTAClass::config (this=0x0, local_ip=..., gateway=..., subnet=..., dns1=..., dns2=...)
    at C:\Users\gmanw\AppData\Local\Arduino15\packages\esp32\hardware\esp32\3.3.4\libraries\Network\src/NetworkInterface.h:41
#1  0x4008c4c0 in vPortTaskWrapper (pxCode=0x400e1d84 <WiFiSTAClass::config(IPAddress, IPAddress, IPAddress, IPAddress, IPAddress)+476>, pvParameters=0x0)
    at /home/runner/work/esp32-arduino-lib-builder/esp32-arduino-lib-builder/esp-idf/components/freertos/FreeRTOS-Kernel/portable/xtensa/port.c:139
(gdb)

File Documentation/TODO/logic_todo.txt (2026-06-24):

1) remove this from D:\MyArduino\Projects\ESP32_Scale\PropaneScale\src\workflows\startup_tare_workflow.cpp.63:
Not-empty threshold: >= 35.50 lbs (tank tare + max propane + margin).
Stability tolerance: +/- 1.50 lbs once below not-empty threshold.
Timeout expiry with empty + stable readings auto-confirms taring workflow.

I WANT THIS:
Startup tare: waiting for empty scale...
Auto-detect is active.
Auto-detect timeout: 15 seconds
Send 'q' to skip startup tare.

COMPLETED

2) format & add runtime tare offset to output & remove "Propane Level Scale"
NB not sure all states & modes are being output. Check and add if necessary.

from this:

Propane Level Scale

Current Runtime Values
EEPROM ready: yes
Calibration factor: -10420.86
Known calibration weight: 26.00 lbs
Max propane weight: 16.00 lbs
Tank tare: 17.50 lbs
Calibration mode: 0 (NONE)
Calibration state: 0 (IDLE)
Level state: 0 (IDLE)
Tare state: 0 (IDLE)
Input mode: 0 (NONE)
Input state: 0 (IDLE)

to this:

Current Runtime Values
EEPROM ready: yes
Calibration factor: -10420.86
Known calibration weight: 26.00 lbs
Max propane weight: 16.00 lbs
Tank tare: 17.50 lbs
Runtime tare offset: 228748

Calibration mode: 0 (NONE)
Calibration state: 0 (IDLE)
Level state: 0 (IDLE)
Tare state: 0 (IDLE)
Input mode: 0 (NONE)
Input state: 0 (IDLE)

COMPLETED

3) all timeouts can be 15 seconds, so change settling to use CONFIRM_TIMEOUT_MS and remove CAL_SETTLE_DELAY_MS

LEAVE FOR NOW

4) verify InputContext inputCtx; is supposed to be in PropaneScale.ino

YES IT DOES. NEEDED by resetINputContext, WHICH MUST REMAIN IN PropaneScale.ino.

5) have all user input handled by 'handle*Input(char incoming) functions
to modify:
see note
Remove Serial Input Handling from `tickCalibration
calibration_workflow.cpp: handleCalibrationInput

currently existing:
input_known_weight.cpp: handleKnownWeightInput
input_propane_weight.cpp: handlePropaneWeightInput
input_tank_tare.cpp: handleTankTareInput
level_workflow.cpp: handleLevelReadInput

COMPLETED

6) Extract SKIP handling from `tickTare()` on PropaneScale.ino into a dedicated
input handler `handleStartupTareInput()` in the startup tare workflow module.

DONE

7) check if any scale.wait_ready_timeout usage is acceptable in web ble and/or wifi

NO. All have been removed.

8) AvgContext and ThresholdAvgContext are nearly identical.
Keep the minimumThreshold field present (unused) to avoid changing the struct layout and externs; leaving it zero-initialized is fine.
Update the declaration/definition where AvgContext avgCtx exists to ThresholdAvgContext avgCtx.
Verify all call sites and externs in workflows_contexts.h and scale_io.cpp so symbols match.
rename ThresholdAvgContext → AvgContext (single canonical type) for clearer intent.

DONE

9) get agent to propose but not implement:
a reentrant averaging logic level and calibration threshold averaging.
the level and workflow and 3 calibration workflows are never concurrent.
the averaging helper operates on a caller-supplied context so multiple independent samplers can share the same implementation without globals.
do not use a wrapper around non-blocking average units function.
analyze existing usage of non-blocking average units function to ensure proposed reentrant will not cause any regression bugs.

LEAVE FOR NOW

10)  Ask agent to:
a) Review level workflow pattern, calibration workflow pattern and startup tare pattern.
b) Review input known weight, max propane, and tank workflow patterns
c) review current runtime values, default eeprom, & help workflow patterns

What I want to know is where respective patterns are "out of sync"
and what ramifications are.

TODO

11) Startup tare timeout check: reading=0.00 lbs, baseline=0.00 lbs
I don't need to see this if reading & baseline are within established zero params.
I only need to see startup tare timeout check on negative weight or true positive weight

LEAVE

12) review all printing logic!

what costs more in ram/cycles:
this kind of print pattern:
Serial.print("Attempting STA connect to: ");
Serial.println(WIFI_SSID);

or this kind:
char buf[128];
unsigned long loadDetectSeconds = CONFIRM_TIMEOUT_MS / 1000UL;
snprintf(buf, sizeof(buf), "Waiting for weight placement on scale...\nSend 'q' to cancel.\nLoad placement timeout: %lu seconds.\n", loadDetectSeconds);
queueSerialOutput(buf);

Short answer: the snprintf path costs more — both RAM (stack) and CPU cycles — than the two-call Serial.print/println approach.

Why:

RAM: snprintf(buf,128,...) allocates the full buffer on the stack (here 128 bytes) plus snprintf's internal temporaries. Two Serial.print calls use essentially no extra stack (they read the strings from flash/data).
CPU: snprintf does parsing/formatting and integer -> ASCII conversion (divides/mods), which is relatively expensive. Two Serial.print calls do far less work (just stream the literal and the string/number to the driver).
Additional cost caveat: if queueSerialOutput() copies the string into a queue/heap, that adds heap/RAM; multiple small prints may avoid a large transient copy but do more driver calls.
Recommendation:

If you only concatenate a literal and a number, prefer multiple Serial.print calls (use F("...") for flash-stored literals) to minimize stack and cycles:
Serial.print(F("Waiting for weight placement on scale...\nSend 'q' to cancel.\nLoad placement timeout: "));
Serial.println(loadDetectSeconds);
Use snprintf only when you need complex formatting or a single contiguous string (or when you must queue a single buffer).

13) Replace manual JSON assembly with a lightweight JSON helper or library for robustness.
TO REVIEW

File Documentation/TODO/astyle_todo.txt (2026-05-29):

1) verify Astyle is running on file save
2) verify Astyle is running pre-commit
3) verify Astyle running on git hub
4) REVIEW aSTYLE RULES
  a) want 1 space after //
  b) no trailing spaces
  c) global class vars: PascalCase eg HX711 Scale;
  d) global vars: PascalCase eg float CalibrationFactor = 0.0f;
  e) global constants: ALL_CAPS eg extern const char CALIBRATION_SAVE_FAILURE_MSG[];
  f) structs: PascalCase eg struct CalContext
  g) struct members: camelCase eg int    totalReadings     = 0;
  h) enums: PascalCase eg enum class CalState : uint8_t {
  i) enum members: ALL_CAPS eg WAIT_EMPTY = 1
  j) local vars: camelCase eg bool haveSample = false;
  k) local constants: camelCase eg const int probeReads = LIVE_SAMPLES;
  l) functions: camelCase eg static bool queueSerialOutput

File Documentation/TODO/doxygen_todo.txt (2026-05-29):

1) Determine what doxygen formatting I want
  a) Should #include statements have /**< ipsum lorem */ ?
2) Review all files per formatting

3) remove all:
 *
 * @throws {none} This function does not throw exceptions.

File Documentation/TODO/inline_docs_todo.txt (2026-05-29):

1) review all file for accurate & pertinent "why" comments

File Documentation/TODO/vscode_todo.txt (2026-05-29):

1) add a task that launches coolterm
can have optional input file dialog for settings file

2) get all openOcd/esp-prog debug tasks working

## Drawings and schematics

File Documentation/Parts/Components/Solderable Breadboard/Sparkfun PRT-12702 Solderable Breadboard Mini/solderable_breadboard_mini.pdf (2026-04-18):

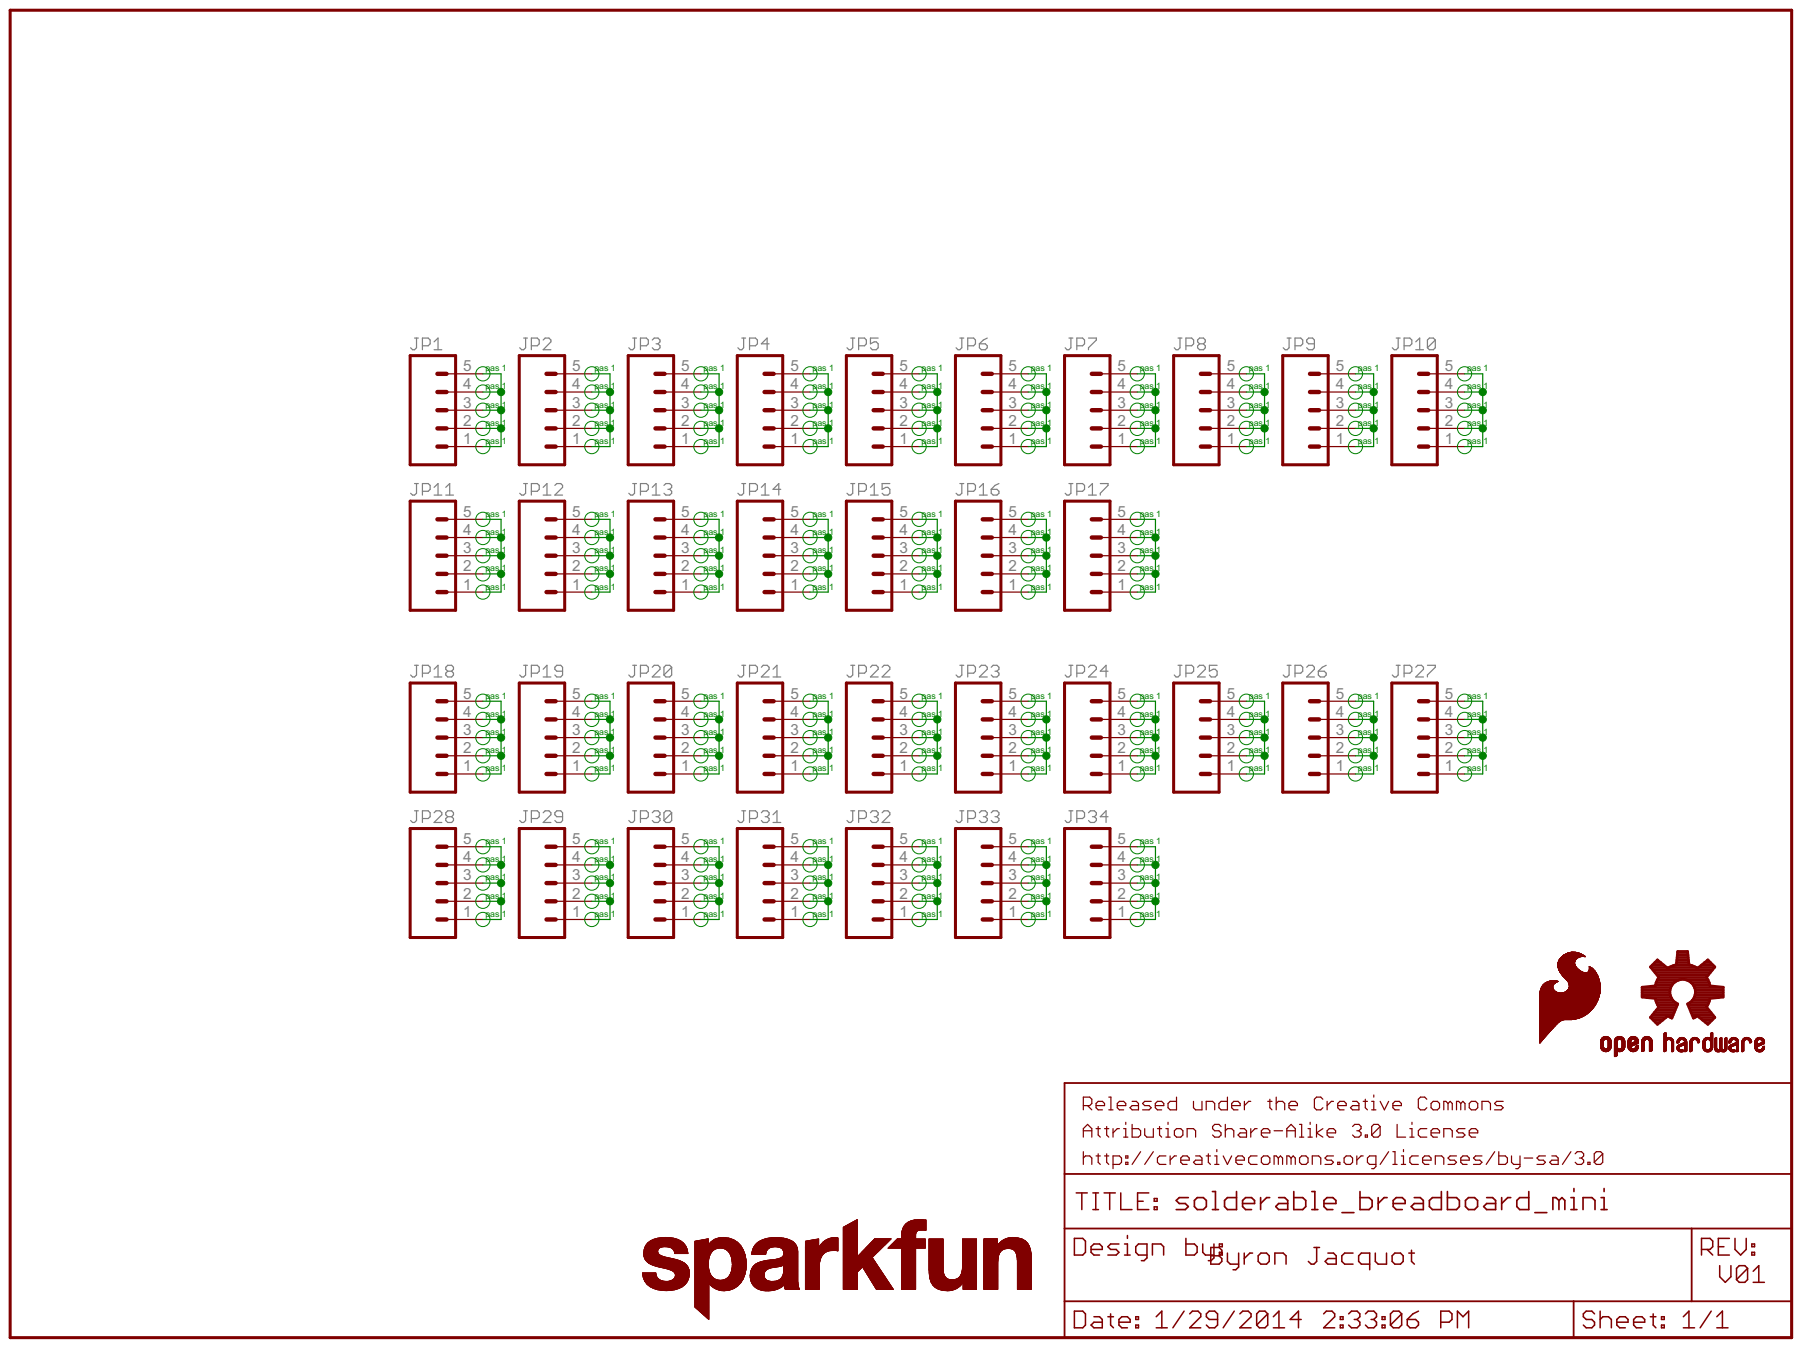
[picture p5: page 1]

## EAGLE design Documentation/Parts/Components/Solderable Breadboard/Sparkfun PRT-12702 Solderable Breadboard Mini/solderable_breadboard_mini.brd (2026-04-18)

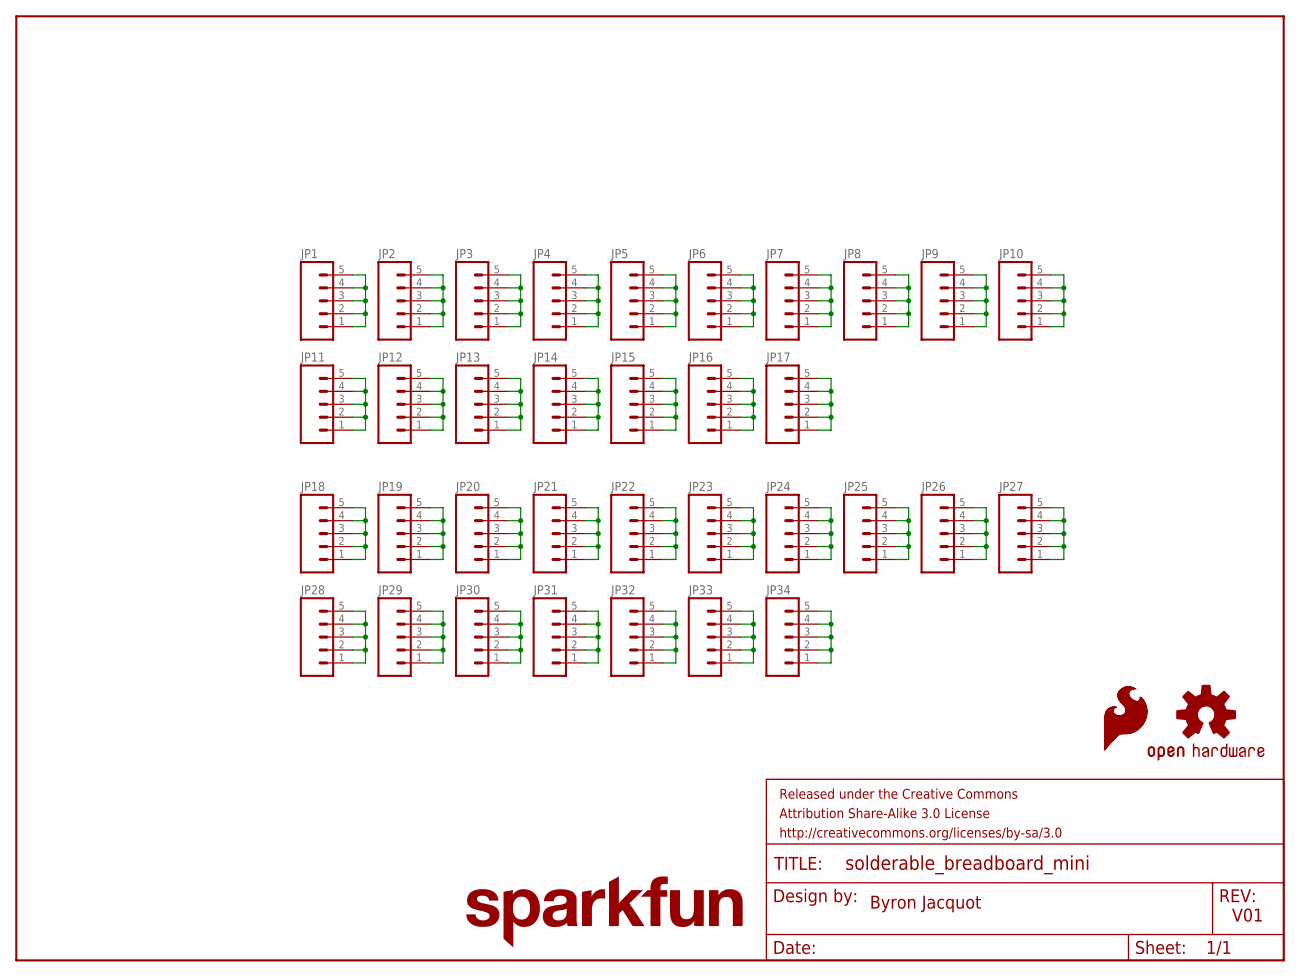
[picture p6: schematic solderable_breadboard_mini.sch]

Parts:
FRAME1: FRAME-LETTER; CREATIVE_COMMONS
JP1, JP2, JP3, JP4, JP5, JP6, JP7, JP8, JP9, JP10, JP11, JP12, JP13, JP14, JP15, JP16, JP17, JP18, JP19, JP20, JP21, JP22, JP23, JP24, JP25, JP26, JP27, JP28, JP29, JP30, JP31, JP32, JP33, JP34: 1X05_NO_SILK
LOGO1: SFE_LOGO_NAME.1_INCH; SFE_LOGO_NAME_.1
LOGO2: OSHW-LOGOM; OSHW-LOGO-M
LOGO3, LOGO4: SFE_LOGO_FLAME.1_INCH; SFE_LOGO_FLAME_.1

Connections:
unnamed: JP1.1, JP1.2, JP1.3, JP1.4, JP1.5
unnamed: JP2.1, JP2.2, JP2.3, JP2.4, JP2.5
unnamed: JP3.1, JP3.2, JP3.3, JP3.4, JP3.5
unnamed: JP4.1, JP4.2, JP4.3, JP4.4, JP4.5
unnamed: JP5.1, JP5.2, JP5.3, JP5.4, JP5.5
unnamed: JP6.1, JP6.2, JP6.3, JP6.4, JP6.5
unnamed: JP7.1, JP7.2, JP7.3, JP7.4, JP7.5
unnamed: JP8.1, JP8.2, JP8.3, JP8.4, JP8.5
unnamed: JP9.1, JP9.2, JP9.3, JP9.4, JP9.5
unnamed: JP10.1, JP10.2, JP10.3, JP10.4, JP10.5
unnamed: JP11.1, JP11.2, JP11.3, JP11.4, JP11.5
unnamed: JP12.1, JP12.2, JP12.3, JP12.4, JP12.5
unnamed: JP13.1, JP13.2, JP13.3, JP13.4, JP13.5
unnamed: JP14.1, JP14.2, JP14.3, JP14.4, JP14.5
unnamed: JP15.1, JP15.2, JP15.3, JP15.4, JP15.5
unnamed: JP16.1, JP16.2, JP16.3, JP16.4, JP16.5
unnamed: JP17.1, JP17.2, JP17.3, JP17.4, JP17.5
unnamed: JP18.1, JP18.2, JP18.3, JP18.4, JP18.5
unnamed: JP19.1, JP19.2, JP19.3, JP19.4, JP19.5
unnamed: JP20.1, JP20.2, JP20.3, JP20.4, JP20.5
unnamed: JP21.1, JP21.2, JP21.3, JP21.4, JP21.5
unnamed: JP22.1, JP22.2, JP22.3, JP22.4, JP22.5
unnamed: JP23.1, JP23.2, JP23.3, JP23.4, JP23.5
unnamed: JP24.1, JP24.2, JP24.3, JP24.4, JP24.5
unnamed: JP25.1, JP25.2, JP25.3, JP25.4, JP25.5
unnamed: JP26.1, JP26.2, JP26.3, JP26.4, JP26.5
unnamed: JP27.1, JP27.2, JP27.3, JP27.4, JP27.5
unnamed: JP28.1, JP28.2, JP28.3, JP28.4, JP28.5
unnamed: JP29.1, JP29.2, JP29.3, JP29.4, JP29.5
unnamed: JP30.1, JP30.2, JP30.3, JP30.4, JP30.5
unnamed: JP31.1, JP31.2, JP31.3, JP31.4, JP31.5
unnamed: JP32.1, JP32.2, JP32.3, JP32.4, JP32.5
unnamed: JP33.1, JP33.2, JP33.3, JP33.4, JP33.5
unnamed: JP34.1, JP34.2, JP34.3, JP34.4, JP34.5

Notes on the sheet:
Byron Jacquot
V01

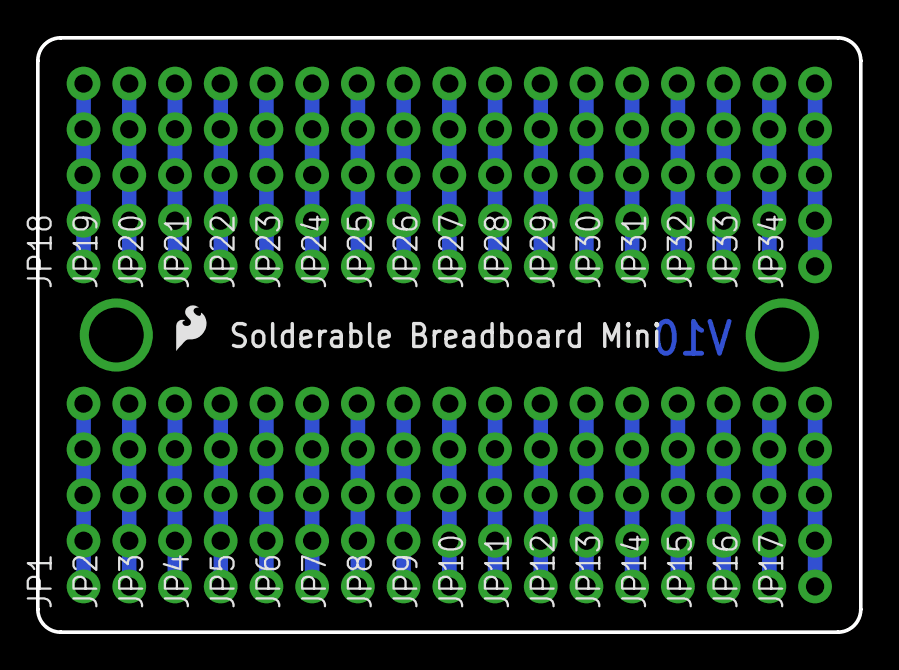
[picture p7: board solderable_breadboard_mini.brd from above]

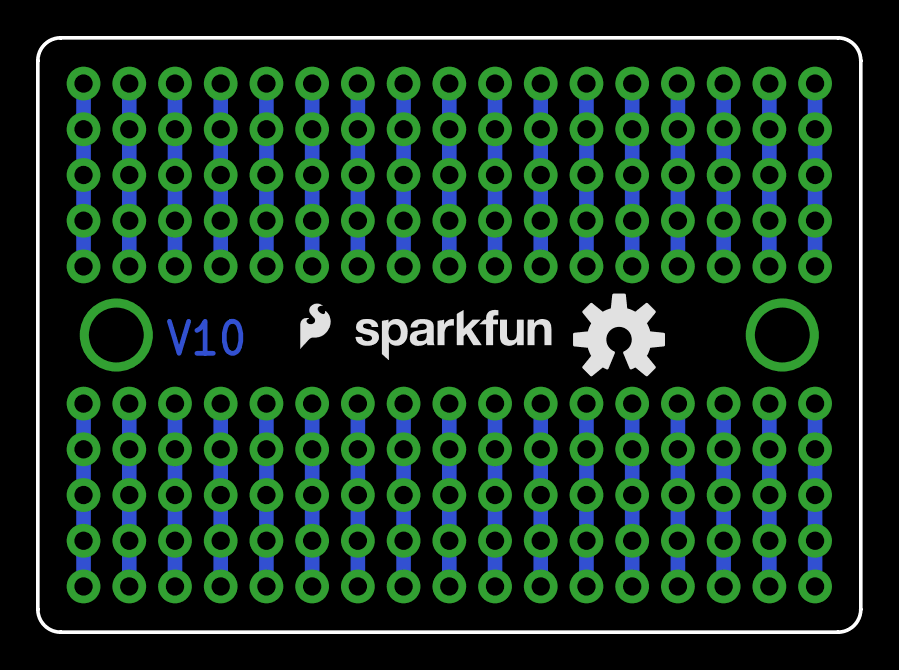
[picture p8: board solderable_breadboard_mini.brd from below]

Board: 2 copper layers, 45.7 x 33.0 mm, 39 parts (3 on the bottom side), 34 nets.

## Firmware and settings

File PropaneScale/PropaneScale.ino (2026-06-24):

/**
 * @file PropaneScale.ino
 * @author Gerald Manweiler
 *
 * @brief Main application file for ESP32-based propane level scale using HX711 amplifier.
 *
 * @details Implements serial command interface for calibration and weight reporting,
 * manages HX711 interactions, and applies calibration factors to convert raw readings to weight in pounds.
 *
 * @version 0.1
 * @date 2024-06-01
 * @copyright Copyright (c) 2024 Gerald Manweiler
 */

// Third party library headers
#include "HX711.h"                                          // HX711 library for interfacing with the load cell amplifier to read weight data

//Local library headers
#include "config.h"                                         // Configuration constants for the ESP32-based propane level scale
#include "src/app_startup.h"                                // Application startup initialization functions
#include "src/commands.h"                                   // Command processing functions for serial interface
#include "src/eeprom_store.h"                               // EEPROM storage functions
#include "src/parsing_utils.h"                              // Utility functions for validating and parsing input values
#include "src/runtime_report.h"                             // Declarations for runtime reporting functions
#include "src/scale_io.h"                                   // Input/output functions for user workflows and HX711 interactions
#include "src/workflows/input_context.h"                    // Input context definitions for non-blocking user input workflows
#include "src/workflows/input_known_weight.h"               // Handlers for the known weight update workflow
#include "src/workflows/input_propane_weight.h"             // Handlers for the max propane weight update workflow
#include "src/workflows/input_tank_tare.h"                  // Handlers for the tank tare weight update workflow
#include "src/workflows/level_workflow.h"                   // Functions for the liquid level read workflow
#include "src/workflows/workflows_contexts.h"               // Context definitions for non-blocking workflows
#include "src/workflows/startup_tare_workflow.h"            // Functions for the startup tare workflow
#include "src/workflows/calibration_workflow.h"             // Functions for the calibration workflow

// Global Class Instances
HX711 scale;                                                /**< HX711 instance for interacting with the load cell amplifier */

// Global State Variables
float calibrationFactor = 0.0f;                             /**< Calibration factor for converting raw HX711 readings to weight in pounds */
bool eepromReady = false;                                   /**< Flag to track if EEPROM was successfully initialized */
float knownWeight = 0.0f;                                   /**< Known weight for calibration */
float maxPropane = 0.0f;                                    /**< Maximum legal propane weight in pounds */
float tankTare = 0.0f;                                      /**< Tare weight of the empty propane tank in pounds */

// State Machine Variables
CalContext calCtx;                                          /**< Calibration context instance to hold state for calibration workflows */
InputContext inputCtx;                                      /**< Non-blocking input context for serial workflows */
LevelContext levelCtx;                                      /**< Level read context instance to hold state for the level read workflow */
TareContext tareCtx;                                        /**< Startup tare context instance */

// Definitions & Declarations for State Machine Functions

/**
 * @brief Resets the input context to its initial state.
 *
 * @details Resets the mode & state, index, parsed value, and buffer to default values.
 * Called at the end of each input workflow to prepare for the next one.
 * Defined & declared here so accessible for input workflows without circular dependencies.
 *
 * @throws {none} This function does not throw exceptions.
 */
void resetInputContext()
{
  inputCtx.mode = InputMode::NONE;
  inputCtx.state = InputState::IDLE;
  inputCtx.index = 0;
  inputCtx.parsedValue = 0.0f;
  inputCtx.buffer[0] = '\0';
}

// Definitions & Declarations for Project lifecycle functions

/**
 * @brief Initializes the application and starts the startup tare workflow.
 *
 * @details Initializes the serial interface, sets up the HX711 scale, applies calibration from EEPROM,
 * and begins the startup tare workflow.
 *
 * @throws {none} This function does not throw exceptions.
 */
void setup()
{
  Serial.begin(BAUD);

  Serial.println();
  Serial.println(APP_TITLE);

  initializeApp();
  beginStartupTare();
}

/**
 * @brief Main application loop that processes serial input and advances workflows.
 *
 * @details Advances the calibration, level read, and tare workflows on each iteration.
 * Processes serial input for workflow interactions and command dispatch.
 *
 * @throws {none} This function does not throw exceptions.
 */
void loop()
{
  // can't have any queued serial output before processing new input or advancing workflows
  drainQueuedSerialOutput();

  // tickTare has to preempt all other workflows and user input until complete,
  // to guarantee stable tare condition before allowing any other interactions or workflows to run
  tickTare();

  if (tareCtx.state != TareState::IDLE) {
    // While startup tare is active, keep serial reads centralized here and
    // forward to the startup tare input handler so user can send 'q' to skip.
    if (Serial.available()) {
      char temp = Serial.read();
      handleStartupTareInput(temp);
    }

    return;
  }

  // Advance other active state machines each iteration
  tickLevelRead();
  tickCalibration();

  // On no serial input, need return so state machines can continue running until next loop iteration
  if (!Serial.available()) {
    return;
  }

  char temp = Serial.read();

  // level read is raison d'etre of this project,
  // it goes after taring is stable to ensure no interference from anything else
  if (levelCtx.state != LevelState::IDLE) {
    handleLevelReadInput(temp);
    return;
  }

  // multi-character input workflows all require user hit enter after inputting new value,
  // do not interact with the scale hardware at all, and have unique input handling requirements
  // tank tare & propane weight likely to be used in preparation for level workflow,
  // and may require a calibration workflow afterward
  // known weight likely to used in preparation for calibration workflow

  if (inputCtx.mode == InputMode::TANK_TARE) {
    handleTankTareInput(temp);
    return;
  }

  if (inputCtx.mode == InputMode::PROPANE_WEIGHT) {
    handlePropaneWeightInput(temp);
    return;
  }

  if (inputCtx.mode == InputMode::KNOWN_WEIGHT) {
    handleKnownWeightInput(temp);
    return;
  }

  // Don't want accidentally triggered multiple commands in a row
  // MUST come after all the input handlers because user hits enter somewhere in those workflows,
  // so newlines need to be processed by handlers but ignored for general command dispatch
  if (temp == '\r' || temp == '\n') {
    return;
  }

  // calibration workflows (especially manual) are special workflows that require single-character command to start,
  // do interact with the scale hardware, and have unique input handling and display logic separate from the other multi-character input workflows,
  // so they go after the input context workflow checks but before the single-character command dispatch
  if (calCtx.state != CalState::IDLE) {
    handleCalibrationInput(temp);
    return;
  }

  bool handled = true;

  // by having empty lower case input cases, do not need to call tolower() on the input
  // this allows the user to send either upper or lower case commands
  // without needing to worry about case sensitivity
  switch (temp) {
  case 'a':
  case 'A':
    automaticCalibration();
    break;

  case 'c':
  case 'C':
    currentRuntimeValues();
    break;

  case 'd':
  case 'D':
    defaultEeprom();
    break;

  case 'e':
  case 'E':
    eepromValues();
    break;

  case 'h':
  case 'H':
    helpMenu();
    break;

  case 'k':
  case 'K':
    knownWeightUpdate();
    break;

  case 'l':
  case 'L':
    liquidLevel();
    break;

  case 'm':
  case 'M':
    manualCalibration();
    break;

  case 'p':
  case 'P':
    propaneWeightUpdate();
    break;

  case 'r':
  case 'R':
    reZero();
    break;

  case 't':
  case 'T':
    tankTareUpdate();
    break;

  default:
    handled = false;
    Serial.print("Unknown command: '");
    Serial.print(temp);
    Serial.println("'. Send 'h' for help.");
    break;
  }

  // flush any extra input after handling a command to prevent accidental multiple command triggers from a single line of input
  if (handled && inputCtx.mode == InputMode::NONE) {
    flushSerialInput();
  }
}

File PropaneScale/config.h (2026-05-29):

/**
 * @file config.h
 * @author Gerald Manweiler
 *
 * @brief Configuration constants for the ESP32-based propane level scale.
 *
 * @details Defines constants used throughout the PropaneScale application.
 *
 * @version 0.1
 * @date 2026-05-06
 *
 * @copyright Copyright (c) 2026 Gerald Manweiler
 *
 */

#pragma once

// ESP32 Hardware Constants
constexpr int CLK_PIN  = 17;                                /**< Clock pin can be changed to any other GPIO pin if needed */
constexpr int DOUT_PIN = 16;                                /**< Data output pin can be changed to any other GPIO pin if needed */

// Serial Communication Constants
constexpr long BAUD = 115200;                               /**< Serial connection speed in bits per second */

// Sampling Constants
constexpr int AVG_SAMPLES        = 1;                       /**< Single sample used in polling loops for detection only */
constexpr int CAL_SAMPLES        = 5;                       /**< Number of samples to average for calibration readings */
constexpr int LIVE_SAMPLES       = 10;                      /**< Number of samples to average for live weight readings (~1s at 10 SPS) */
constexpr int UNLOAD_CHECK_COUNT = 3;                       /**< Shared sample/check count for unloaded averaging and stable-empty confirmation */

// Workflow Constants
constexpr float CHANGE_WARN_PCT = 0.25f;                    /**< Threshold for significant change in tank tare or max propane weight warning */

// wire spool @ 19.2 lbs: -11551.08f;
// half full water jug/milk crate @ 26.0 lbs: -10420.86f;
// kitty litter jug of water @ 36.8 lbs: -10422.95f
constexpr float DEF_CALIBRATION_FACTOR = -10420.86f;        /**< Calibration factor used by HX711 conversion */

// wire spool @ 19.2 lbs good for almost empty 20 lb tank
// half full water jug/milk crate @ 26.0 lbs (h20 @ 23 lbs + milk crate @ 3 lbs) perfect for half full 20 lb tank
// kitty litter jug of water @ 36.8 lbs perfect for half full 30 lb tank
constexpr float DEF_KNOWN_WEIGHT = 26.0f;                   /**< Default known weight lbs for calibration if no valid value found in EEPROM */

// 20 lb tank legal propane weight: 20.0 x 0.80 = 16.0 lbs
// 30 lb tank legal propane weight: 30.0 x 0.80 = 24.0 lbs
constexpr float DEF_MAX_PROPANE = 16.0f;                    /**< Default maximum legal propane lbs is 80% of tank capacity */

// Tare weight of the empty twenty lb tank in pounds is approximately 16-19 lbs
// Tare weight of the empty thirty lb tank in pounds is typically 23-26 lbs
constexpr float DEF_TANK_TARE = 17.5f;                      /**< Default tare lbs of empty tank, subtract from readings for weight of propane */

constexpr float MINIMUM_LOAD_WEIGHT = 1.0f;                 /**< Minimum load in lbs to detect tank placement during level read workflow */

// Non-blocking Timing Constants
constexpr unsigned long CAL_SETTLE_DELAY_MS = 5000UL;       /**< Time to wait for load to mechanically settle before taking calibration reading */
constexpr unsigned long CONFIRM_TIMEOUT_MS  = 15000UL;      /**< Wait time for user &auto confirmations during startup tare workflow/calibration */
constexpr unsigned long POLL_TIMEOUT_MS     = 1000UL;       /**< Maximum time to wait for the HX711 to become ready during polling */
constexpr unsigned long READY_TIMEOUT_MS    = 100UL;        /**< Maximum time to wait for the HX711 to become ready during blocking reads */
constexpr unsigned long STARTUP_TIMEOUT_MS  = 1500UL;       /**< Maximum time to wait for stable readings during startup tare workflow */

// Startup Tare Constants
constexpr float SETUP_EMPTY_WEIGHT           = 1.5f;        /**< Tolerance in lbs for detecting stable empty condition during startup calibration */
constexpr float STARTUP_NOT_EMPTY_MARGIN_LBS = 2.0f;        /**< Margin above configured full-tank weight when deciding startup not-empty condition */

// Scale Physical Components Constants
constexpr float  PLATEN_TARE = 0.33125f;                    /**< Tare lbs of the scale platen in pounds */
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

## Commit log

2026-04-11 init setup
    [esp32_propane_scale.fzz]
2026-04-17 doc reorg
    [esp32_propane_scale.fzz]
2026-04-18 added solderable breadboard mini eagle & pdf
    [solderable_breadboard_mini.brd, solderable_breadboard_mini.sch]
2026-04-23 update fritzing
    [esp32_propane_scale.fzz]
2026-04-23 working manul calibration function
2026-04-24 added auto calibrate funtion
2026-04-24 solid working auto and manual calibration functions
2026-04-25 added calibration factor eeprom handling
2026-04-25 updated using full length protoboard
    [esp32_propane_scale_v2.fzz]
2026-04-27 avoided infinite block in setup
    [PropaneScale.ino, config.h]
2026-04-27 calibration workflows non-blocking
2026-04-28 update wiring
2026-04-28 fix comment mismatch ad esnure eeprom begin guard
    [PropaneScale.ino, config.h]
2026-04-29 improve calibration logic and reduce repeated threshold code
2026-04-30 fixed helpmenu casing typo
    [PropaneScale.ino]
2026-04-30 add direct esp32 full compile
2026-04-30 fix opening banner print spacing
    [PropaneScale.ino]
2026-05-01 added some stl files
    [LoadCell-StrainGaugePlatform.stl, Load_cell_HX711_5kg_12.7x80_M4_M5.stl]
2026-05-01 using state machine to go non-blocking in calibration workflow
2026-05-03 update comments & error messages
    [PropaneScale.ino]
2026-05-03 ensure startup summary fully prints
2026-05-03 added current runtime values & myabe fixed late startup printing
    [PropaneScale.ino, config.h]
2026-05-04 stl updates
    [Bottom Plate v1.stl, LoadCell-StrainGaugePlatform.stl, Load_cell_HX711_5kg_12.7x80_M4_M5.stl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]
2026-05-04 prpb fixed terminal output issue
    [PropaneScale.ino]
2026-05-04 guards against HX711 becoming uninitialized due to power down and/or disconnection
2026-05-04 split sampling constants by use case
2026-05-05 added help message and printing enum vals and text
2026-05-05 update todo for switching to web interface
2026-05-05 Reduce Serial.print fragmentation for startup/banner paths
2026-05-05 reduce serial.print fragmentation
2026-05-05 remove unnecessary Serial.print*(F(
2026-05-06 update lis_ports for project hard coded for esp32
2026-05-06 at chunk step 3
    [Manual Refactoring.xlsx]
2026-05-07 create scale io module
    [Manual Refactoring.xlsx]
2026-05-08 added powershell * modded quick flash task
2026-05-08 chunk2 step 1 Create shared input context header
    [Manual Refactoring.xlsx]
2026-05-08 Extract known weight workflow
    [Manual Refactoring.xlsx]
2026-05-08 Extract max propane workflow
    [Manual Refactoring.xlsx]
2026-05-08 Extract tank tare workflow
    [Manual Refactoring.xlsx]
2026-05-08 chunk 2 steps 5 & 6
    [Manual Refactoring.xlsx]
2026-05-08 chunk 3 step 0 base compile
    [Manual Refactoring.xlsx]
2026-05-08 Extract level workflow
    [Manual Refactoring.xlsx]
2026-05-09 fix startup with weight on scale bug
    [PropaneScale.ino]
2026-05-09 extract startup tare flow *and fixed lod on startup bug)
    [Manual Refactoring.xlsx]
2026-05-09 chunk3 step 2.5 extract runtime persistence helper
    [Manual Refactoring.xlsx]
2026-05-09 chunk3 finished (calibration workflow extracted)
    [Manual Refactoring.xlsx]
2026-05-11 changed clock pin
2026-05-11 fixed re-zero not accepting cancel in time
    [config.h]
2026-05-14 extract eeprom reset command
    [PropaneScale.ino, commands.cpp, config.h]
2026-05-16 guard on large prints
2026-05-28 removed missed wifi stuff
    [PropaneScale.ino]
2026-05-28 print cleanups
2026-05-29 Update CI workflow to install HX711 library
    Replaced NimBLE-Arduino library installation with HX711 library installation in CI workflow.
2026-06-24 cherry pick updates & adds from wifi branch
    [esp32_propane_scale_v2.fzz, required-esp32.cfg, required-esp32_devkitj_v1.cfg]

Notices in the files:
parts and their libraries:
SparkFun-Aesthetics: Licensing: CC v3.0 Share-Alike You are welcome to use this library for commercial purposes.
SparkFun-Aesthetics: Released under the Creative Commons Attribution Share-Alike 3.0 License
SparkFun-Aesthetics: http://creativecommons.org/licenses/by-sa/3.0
